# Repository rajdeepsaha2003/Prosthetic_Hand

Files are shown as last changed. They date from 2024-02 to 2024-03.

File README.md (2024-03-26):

# An EMG based cost effective Prosthetic hand 

**Rajdeep Saha, Abhijit Biswas, Saradwat Sen and Sayani Dhali**

**Department of Electronics and Communications Engineering, Supreme Knowledge Foundation Group of Institution, 11, Khan Road, Mankundu, DistrictWest Bengal, Hooghly 712139, India**

**Abstract**   In the era of assistive technology, the need for affordable and accessible prosthetic solutions has been roaming around forever. We introduce the solution by making an inexpensive prosthetic arm controlled by electromyographic (EMG) signals obtained from the upper arm muscles of amputees. This project addresses a major global issue which is, in an estimate over 100 million individuals worldwide require prosthetic limbs due to limb damage or amputation. Unfortunately, a large portion of these individuals (especially those from lower economic backgrounds) face problems accessing due to the high cost of traditional prosthetic options, which can range from Rs70,000 to Rs3.5 lakh for imported prosthetic hands. But this project is Remarkably cost-effective. The overall system costs around a few thousand rupees significantly reducing expenses compared to market alternatives. This project solves the solution by using cost-effective technologies in the most efficient ways. The key component in this prosthetic hand is the Muscle EMG sensor. The noise reduction and the amplification of the Bio-Potential signal is done in the IC of the EMG sensor, which helps in precise signal acquisition. By integrating this sensor into the prosthetic hand design, the component can accurately capture muscle signals and translate them into commands for prosthetic hand movements. The brain of this prosthetic hand is a microcontroller, which serves as the central processing unit for signal processing as Band-Pass Butterworth IIR digital filter and responsiveness. Through confined algorithms and real-time data analysis, the microcontroller reads EMG signals captured by the sensor, enabling full control of the prosthetic hand. This integration of hardware and software makes the project's goal of affordability without compromising performance possible. Beyond the technical aspects, this project solves the topmost prioritized problem which is affordability with efficiency. In third world countries where a large portion of people are suffering through poverty, surgery on amputation is nowhere near possible, let alone installing prosthetics. This cheap but effective alternative which costs around 1-3% of the market's product cost, can be affordable to the mass population with disabilities and enhance their quality of life.

**Keywords:** EMG Signal, Bio-Potential Amplifier, Band-Pass Butterworth IIR digital filter

**1. Introduction**

Prosthetics are artificial devices that compensate for the lack of existence of limbs throughout the body. A prosthetic arm replaces the amputated or inoperative upper limbs. This offers individuals who have lost limbs a chance to regain mobility and independence. Now unlike traditional prosthetic arms, a Myoelectric Prosthetic arm is controllable by myoelectric (EMG) signals expediently. This is made achievable by the fact that amputees' neuro-muscular systems continue to function normally even after amputation. After appropriate processing, the leftover signals are utilized and are sufficient to control the arm's movement. [16]. The technical approach of Sudesh Garg, Kiran Rathi, and Amit Kr. Bansal is concentrated on creating a 3D-printed bionic arm that prioritizes human control via EMG sensors, affordability, and usefulness. It is possible to fabricate objects that are lightweight and customizable by using PLA and 3D printing technology. Evaluating for necessary hand movements guarantees usability and imitation of natural hand movements. The objective is to offer amputees an affordable and easily obtainable option that prioritizes controllability and enhanced quality of life. However, noise filtering methods are not specifically mentioned [9]. Furthermore, to separate muscle signals from outside interference in EMG-based systems, noise filtering techniques are crucial for precise bionic arm control as well as improved user experience and safety.

The research aim focuses on decreasing external noise interference that occurs during signal transmission from the brain to the skin of the targeted muscle location. We successfully reduced this interference by utilizing the Butterworth digital filter, which guarantees more precise and more accurate signal capture. This advanced filtering system is indispensable to improve the prosthetic device's overall reliability and effectiveness.

The merit of the following research lies within the cost factor of the prosthetic arm. It has been estimated that there are roughly 0.62 amputees in India per thousand population [17].  With that number of amputees, we are aware that the traditional EMG-controlled prosthetic’s pricings are way beyond affordable for the lower-income groups. This cheap but efficient controllable prosthetic arm will be viable for every individual regardless of their monetary situation.

In addition, we have added a manually operated radical feature that makes it quite effortless for users to hold a pen and write. With the help of this unique feature, people with upper limb disabilities can now write with greater confidence and ease.

**2. Methodology**

The initial step involves using dry surface electrodes to gather EMG data from the patient's hand. For EMG sensors, three electrodes are employed: two for recording the signal and one as a reference. When targeting specific muscles like the forearm, one electrode is placed at the muscle's center, and the other at a distance of 1.5 inches. The reference electrode is positioned on the bony side or the back side of the forearm. 

To minimize electrode-to-skin impedance, the electrodes are pre-gelled. Before applying the electrodes, the skin is sanitized. The collected EMG data are then analyzed to detect forearm movement and distinguish between hand states such as flexion and extension.[15]

**2.1 Acquisition of signal using Muscle BioAmp Band**

Three electrodes are used here to capture the EMG signal from the muscle of the forearm. Two of them are bipolar surface electrodes and one is a reference electrode. Then the signal is sent to the Muscle BioAmp Candy through BioAmp Cable and then to the Arduino Nano for further processing.
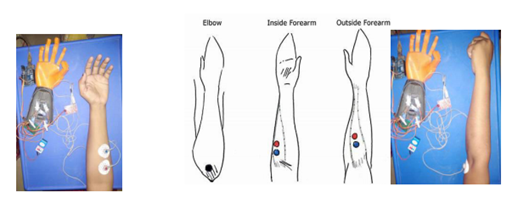
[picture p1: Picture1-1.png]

Figure 1 Electrodes placement for signal acquisition

**2.2 Control of The Prosthetic Hand** 

The prosthetic hand was designed to assist the hand's elbow motions by using signals derived from wrist motions. The EMG signals were processed and then delivered as control signals to an Arduino Nano. Wrist flexion is the signal that is obtained if the person closes their hand or flexes their forearm muscle.

` `This results in the motor rotating in an upward and downward direction, enabling the hands of individuals who are amputated to open and close the hand, and grasp objects. The Arduino Nano's PWM ports are connected to the motor's control input, which is powered by an external source. 

Consequently, the prosthetic hand was successfully operated using EMG signals that were recorded from the healthy hand. [15]

**						

**3. Components and Parts Used**

**3.1 Muscle-BioAmp-Candy**

Muscle-BioAmp-Candy is a candy-sized Electro Myography (EMG) sensor designed to capture precise muscle bio-potential signals. With a compact size and functionality, this device can transform the way of monitoring muscle activity.

It has a fixed gain of x2420 and a Band Pass filter spanning from 72Hz to 720Hz, Muscle-BioAmp-Candy ensures signal clarity and accuracy. 

Compatible with standalone ADCs such as the ADS1115 or any microcontroller development board equipped with an ADC, Muscle-BioAmp-Candy offers seamless integration into your existing setup. [1]

Figure 3 Muscle-BioAmp-Candy [1]

**Schematic Diagram-**

**3.2 Muscle BioAmp Band (EMG Band)**

Stretchable in nature, the Muscle BioAmp Band (EMG Band) can be linked to the Muscle BioAmp-Candy via a BioAmp Cable that uses dry electrodes. It makes it simple for you to capture your muscle signals.[14]

**Dimensions:**

**			 

**Features & Specifications**

Length: 13 inches

Stretchability: 2X (up to 26 inches)

Usability: Reusable as it comes with washable fabric

Interface: Snap electrodes

Compatible Hardware: BioAmp Cable used with BioAmp Hardware (Muscle BioAmp BisCute, Muscle BioAmp Candy, Muscle BioAmp Patchy, BioAmp EXG Pill, Muscle BioAmp Shield)

BioPotentials: EMG

No. of channels: 1

Wearable: Yes

Figure 6 Electrode Placement Example [14]

**3.2** **Arduino Nano**

Figure 7 Arduino Nano Board [2]

Arduino Nano is a small, breadboard-friendly development board based on an ATmega 328P SMD package microcontroller and offers the same connectivity and specs as Arduino Uno in a small package. In our project, we are using it because the size is the main factor. After all, the microcontroller needs to be fit into the 3d printed hand. We are supplying the power to the board with a Mini B USB port present on it. [2]

**Specifications:**

- It has 22 I/O pins in total of which 14 are Digital (6 are PWM output) and 8 are Analog pins.
- Operating Voltage (Logic Level): 5V.
- Supports Serial, I2C, SPI Communication Protocols.
- Flash memory: 32KB in which 2KB is used by Bootloader
- Clock speed: 16MHz
- DC Current per I/O Pin: 40 mA
- SRAM: 2KB, EEPROM: 1KB
- DC Current per I/O pin: 40mA[2]

**3.3 SG90 9 g Micro Servo**

Figure 8 SG90 9 g Micro Servo [3]*			Figure 9 Orthographic view of SG90 9 g Micro Servo [3]

SG90 9 g Micro Servo is tiny and lightweight with high output power. The servo motors are used for the movement of the fingers in the hand. The servo motors usually provide control over the 180° range. This angular position control is controlled by the PWM technique so by varying its duty cycle we can control the angular position of the motor. This servo motor can lift a maximum of 1.6 kg when suspended at a 1cm distance from the shaft. [3]

Specifications

• Weight: 9 g

• Dimension: 22.2 x 11.8 x 31 mm approx.

• Stall torque: 1.8 kgf·cm

• Operating speed: 0.1 s/60 degree

• Operating voltage: 4.8 V (~5V)

• Dead band width: 10 µs 

• Temperature range: 0 ºC – 55 ºC [3]

` `Every 20 ms, the servo examines the pulse. The servo can be rotated to zero degrees by a pulse with a width of 1 ms (1 millisecond), to ninety degrees (the neutral position) by a pulse of 1.5 ms, and to 180 degrees by a pulse of 2 ms.. [13]

**3.4 Power Bank**

Figure 11 Reconnect Power Hub 10000 mAh Power Bank Series 100 [4]

Here we are using Reconnect Power Hub 10000 mAh Power Bank Series 100. It has a capacity of 10000 mAh, so it can be used for longer intervals. As the microcontroller, servo, and Muscle-BioAmp-Candy draw very little power on a full charge it lasts for about 10hrs.[4]

Specifications and Features

- Over Charge Protection, Over Discharge Protection
- Over Current Protection, Short Circuit Protection
- Input: 5V 2A(max)
- Type C And Micro USB Dual Input Port
- USB A 5V/2A Output Port
- BIS Certified [4]

**3.5 Fabrication of 3D Printed Hand**

Here we used PLA because PLA is a common 3D printing material to print components. PLA is widely used because of its ease of availability, ecological footprint, and affordability. 
PLA is a biodegradable substance derived from food crops like sugarcane, corn, and jowar. Here are some key characteristics of PLA and the 3D printer [9]:

**Table 1:** Features of PLA[9][10]

|**S.N.**|**Property**|**Value**|
| :-: | :-: | :-: |
|1|Melting Point|Low (150°C and 180°C)|
|2|Thermal Expansion|Low (68 µm/m-K )|
|3|Layer Adhesion|Moderate|
|4|Heat Resistance|Low(55–65 °C)|
|5|Tensile Strength|High(39.9 MPa to 52.5 MPa)|
|6|Compressive Strength|High (48.2 MPa to 62.0 MPa)|
|7|Dimensional Accuracy|High|

**Table 2:** Features of 3D Printer[11]

|**Model**|**Ender 3**|
| :-: | :-: |
|Physical dimensions|(w) 40 cm x (d) 22 cm x (h) 46 cm|
|Maximum printing area|(w) 20 cm x (d) 22 cm x (h) 22 cm|
|Wire diameter|0\.2mm|
|Nozzle diameter|0\.4mm|
|Platform temperature|~100 °C|
|Nozzle printing temperature|~200 °C|
|Cooling method|Air Cool|
|Motor drive|Stepper Motor Drive|

Now let us discuss the specification of the 3D Printed Hand

**Table 3:** Technical Specification of 3D Printed Parts[12]

|**No.**|**Name of the parts**|**No. of joints/parts**|**Length (cm)**|
| :- | :- | :- | :- |
|1|Thumb finger|2|5\.5|
|2|Index finger|3|6|
|3|Middle finger|3|8\.5|
|4|Ring finger|3|7\.5|
|5|Pinky finger|3|5\.5|
|6|Palm|1|10|
|7|Wrist|-|2\.3|
|8|The diameter of the end of the wrist|-|10|
|9|The total length of the arm|-|30|

Figure 12 Isometric projection of the 3D Printed Hand [11]

**4 Algorithms and Their Detailed Analysis**

**4.1 Algorithm of the Arduino Code**

**Initialization:**

1. Set up the system parameters including the header files, sampling rate, baud rate, and pin configurations.
1. Initialize the communication interfaces (e.g., Serial) for monitoring and debugging purposes.

**Setup:**

1. Attach the servo motors to their respective pins and set their initial positions.
1. Define the WritePin
1. Configure the EMG sensor input pin and any auxiliary pins required for system operation.
1. Define the threshold voltage (different for each person)

**Main Loop:**

1. Check WritePin is High or Low 

If High, Rotate the thumb, index, and middle finger as such it can hold a pen for writing purposes

If Low, Continue to the next steps

1. Continuously sample the EMG signal at the defined sampling rate.
1. Apply a band-pass Butterworth IIR digital filter to the raw EMG signal to extract relevant muscle activity within the desired frequency range.
1. Compute the EMG envelope using an envelope detection algorithm to estimate the magnitude of muscle activation.

**Gesture Recognition:**

1. Compare the normalized envelope value with a predefined threshold to determine muscle activation and gesture recognition.
1. Implement a hysteresis mechanism to prevent rapid toggling of the hand due to noise or minor fluctuations in muscle activity.
1. Define specific thresholds for opening and closing gestures based on individual user characteristics and preferences.

**Servo Control:**

1. Based on the detected gesture:
   1. If the muscle activation exceeds the closing threshold:
      1. Close the hand by rotating the servo motors to the predefined closed position.
   1. If the muscle activation falls below the opening threshold:
      1. Open the hand by rotating the servo motors to the predefined open position.
1. Implement a gesture delay to prevent rapid and unintended toggling of the claw in response to minor fluctuations in muscle activity. [1]

**4.2 Algorithm for Envelope Detection-**

1. Subtract the previous EMG signal value from the sum.
1. Add the absolute value of the current EMG signal to the sum.
1. Store the absolute value of the current EMG signal in the circular buffer at the current index.
1. Update the data index to point to the next position in the circular buffer, wrapping around to the beginning if necessary.
1. Compute the average of the EMG signal values in the circular buffer by dividing the sum by the buffer size.
1. Multiply the average by 2 to scale the envelope signal.
1. Return the computed envelope signal.

Figure 14 EMG Signal After Filter with The Detected Envelope [9]

**4.3 Algorithm of EMG Band Pass Filter**

Algorithm for the Band-Pass Butterworth IIR digital filter:

1. **Initialization**:
   1. Initialize the state variables **z1** and **z2** for each filter section to zero.
1. **Filtering Process**:
   1. For each input sample:
      1. For each filter section:
         1. Calculate the intermediate variable **x** using the difference equation of a second-order IIR filter.
         1. Update the output using the calculated **x** value and the previous state variables.
         1. Update the state variables **z1** and **z2** for the next iteration.
1. **Output**:
   1. Return the filtered output.

Here's a breakdown of the steps within the filtering process:

- For each filter section:
  - Calculate the intermediate variable **x** using the difference equation:

x = input - a1 \* z1 - a2 \* z2 

where **input** is the current input sample, **z1,** and **z2** are the previous state variables, and **a1** and **a2** are the filter coefficients.

- Update the output using the calculated **x** value and the previous state variables:

output = b0 \* x + b1 \* z1 + b2 \* z2 

where **b0**, **b1**, and **b2** are the filter coefficients for the output.

- Update the state variables **z1** and **z2** for the next iteration:

z2 = z1 z1 = x 

Repeating these steps for each input sample, obtained the filtered output of the Band-Pass Butterworth IIR digital filter. [1] [5] [6]

**4.4 General Difference Equation of** **Band-Pass Butterworth IIR digital filter**

The code implements a Band-Pass Butterworth IIR digital filter using second-order sections (biquads). Each biquad represents a second-order IIR filter section. Let's break down the mathematical expression for each biquad.

The general difference equation for a second-order IIR filter is:

*y*[*n*]=*b*<sub>0</sub>*x*[*n*]+*b*<sub>1</sub>*x*[*n*−1]+*b*<sub>2</sub>*x*[*n*−2]−*a*<sub>1</sub>*y*[*n*−1]−*a*<sub>2</sub>*y*[*n*−2]

Where:

- *y*[*n*] is the output at time *n*
- *x*[*n*] is the input at time *n*
- *x*[*n*−1] and *x*[*n*−2] are the previous input samples
- *y*[*n*−1] and *y*[*n*−2] are the previous output samples
- *b*<sub>0</sub>,*b*<sub>1</sub>,*b*<sub>2</sub> are the feedforward (numerator) coefficients
- *a*<sub>1</sub>,*a*<sub>2</sub> are the feedback (denominator) coefficients

Let's express each biquad in the code as difference equations:

**First Biquad:**

z1\_1[n] = x[n] - 0.05159732 \* z1\_1[n-1] - 0.36347401 \* z2\_1[n-1] z2\_1[n] = z1\_1[n-1] y\_1[n] = 0.01856301 \* z1\_1[n] + 0.03712602 \* z2\_1[n] + 0.01856301 \* z2\_1[n-1] 

**Second Biquad:**

z1\_2[n] = y\_1[n] - (-0.53945795 \* z1\_2[n-1] - 0.39764934 \* z2\_2[n-1]) z2\_2[n] = z1\_2[n-1] y\_2[n] = 1.00000000 \* z1\_2[n] - 2.00000000 \* z1\_2[n-1] + 1.00000000 \* z2\_2[n-1] 

**Third Biquad:**

z1\_3[n] = y\_2[n] - (0.47319594 \* z1\_3[n-1] - 0.70744137 \* z2\_3[n-1]) z2\_3[n] = z1\_3[n-1] y\_3[n] = 1.00000000 \* z1\_3[n] + 2.00000000 \* z1\_3[n-1] + 1.00000000 \* z2\_3[n-1] 

**Fourth Biquad:**

z1\_4[n] = y\_3[n] - (-1.00211112 \* z1\_4[n-1] - 0.74520226 \* z2\_4[n-1]) z2\_4[n] = z1\_4[n-1] y\_4[n] = 1.00000000 \* z1\_4[n] - 2.00000000 \* z1\_4[n-1] + 1.00000000 \* z2\_4[n-1] 

Where:

- <i>z</i>1<i><sub>i</sub></i>[<i>n</i>] and <i>z</i>2<sub><i>i</i></sub>[<i>n</i>] are the state variables for the <i>i</i>-th biquad at time <i>n</i>
- *x*[*n*] is the input at time *n*
- <i>y<sub>i</sub></i>[<i>n</i>] is the output of the <i>i</i>-th biquad at time <i>n</i>

This set of equations describes the mathematical expression for the given Band-Pass Butterworth IIR digital filter implemented in the provided code. Each biquad contributes to the overall filter response, and the output of one biquad serves as the input to the next biquad in the chain.[5] [6] [7][8]

**4.5 Simulation of BPF in MATLAB**

Here we have simulated the Band-Pass Butterworth IIR digital filter in MATLAB. First we have shown the unfiltered EMG signal acquired from the hand which consists of different frequencies(45Hz, 60Hz, 90Hz, 100Hz and 160Hz) and noise.

Figure 15 Raw EMG signal with multiple frequencies of 45Hz, 60Hz, 90Hz, 100Hz and 160Hz [5][6] [7][8]

And here we have shown the EMG signal after passing through the Band-Pass Butterworth IIR digital filter.

Figure 16 Filtered EMG Signal after Band Pass Filter consisting of frequencies 90Hz and 100Hz [5][6][7][8]

And this is the frequency response of the Band-Pass Butterworth IIR digital filter with -3db point which has a sampling rate: 500.0 Hz, cutoff frequency: [74.5, 149.5] Hz[5][6] [7][8]

Figure 17 Frequency response of the Band-Pass Butterworth IIR digital filter with -3db point [5][6] [7][8]

**5. Testing and Results**

We tested the prosthetic hand with 10 people who have healthy hands and we got these accurate results. We tested 3 things here first how accurately it can grab an object then how accurately it can close and open the hand. 

To have better gripping capability we used hot glue to have a better gripping capability in the most probable contact points when trying to grab any object.

Here are some images that shows how the prosthetic hand looks when at rest and flexed.

Figure 19 Hand at Flexed (Close) Position

To test the accuracy of grabbing any object we have used a round object and a cylindrical object as shown in the Figure 20 and Figure 21.

Now here are the results that we got after testing it on 10 people with heathy hands.

Figure 22 Accuracy of Grabbing Any Object With the Prosthetic Hand

Figure 23 Accuracy of Closing and Opening the Prosthetic Hand

**6. Conclusion**

**References**

1\. GitHub - upsidedownlabs/Muscle-BioAmp-Candy: A candy size ElectroMyoGraphy (EMG) sensor for precise muscle bio-potential signals recording. (n.d.). GitHub. <https://github.com/upsidedownlabs/Muscle-BioAmp-Candy>

2\. Arduino Nano  - Soldered (Without Cable). (n.d.). QuartzComponents. <https://quartzcomponents.com/products/arduino-nano-v3-0-soldered-without-cable?_pos=2&_sid=2bf3b65a9&_ss=r>

3\. SG90 Servo Motor Datasheet. (n.d.). https://components101.com/. Retrieved March 24, 2024, from <https://components101.com/sites/default/files/component_datasheet/SG90%20Servo%20Motor%20Datasheet.pdf>

4\. Reconnect Marvel Spiderman 10000mAh PowerBank, Li-Po battery, 1 USBB output port, Micro USB & Type C dual input, BIS approved, Mobile Accessories- DPB102 SM Online at Best Prices in India - JioMart. (n.d.). JioMart. https://www.jiomart.com/p/electronics/reconnect-marvel-spiderman-10000mah-powerbank-li-po-battery-1-usbb-output-port-micro-usb-type-c-dual-input-bis-approved-mobile-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

5\. scipy.signal.butter — SciPy v1.12.0 Manual. (n.d.). <https://docs.scipy.org/doc/scipy/reference/generated/scipy.signal.butter.html>

6\. Iyer, S. V. (2020, November 30). Digital Filter Design using Python for Power Engineering Applications. Springer Nature. <http://books.google.ie/books?id=jx8MEAAAQBAJ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>

7\. Verma, N. K., & Ghosh, A. K. (2018, July 31). *Computational Intelligence: Theories, Applications and Future Directions - Volume I*. Springer. <http://books.google.ie/books?id=i_pmDwAAQBAJ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>

8\. *Digital filter*. (2023, December 11). Wikipedia. https://en.wikipedia.org/wiki/Digital\_filter#Direct\_form\_II

9\. Garg, S., Rathi, K., & Bansal, A. K. (2023, April 1). Development of 3D Printed Bionic Arm Controlled by EMG Sensor. SKIT Research Journal, 13(1), 13–18. <https://doi.org/10.47904/ijskit.13.1.2023.13-18>

10\. Gao, G., Xu, F., Xu, J., & Liu, Z. (2022, October 10). Study of Material Color Influences on Mechanical Characteristics of Fused Deposition Modeling Parts. *Materials*, *15*(19), 7039. https://doi.org/10.3390/ma15197039

11\. Hsueh, M. H., Lai, C. J., Wang, S. H., Zeng, Y. S., Hsieh, C. H., Pan, C. Y., & Huang, W. C. (2021, May 27). Effect of Printing Parameters on the Thermal and Mechanical Properties of 3D-Printed PLA and PETG, Using Fused Deposition Modeling. *Polymers*, *13*(11), 1758. https://doi.org/10.3390/polym13111758

12\. Sakib, N., & Islam, M.K. (2019). Design and Implementation of an EMG Controlled 3D Printed Prosthetic Arm. *2019 IEEE International Conference on Biomedical Engineering, Computer and Information Technology for Health (BECITHCON)*, 85-88.

13\. *What is a Servo Motor? - Understanding the basics of Servo Motor Working*. (n.d.). <https://circuitdigest.com/article/servo-motor-working-and-basics>

14\. *Muscle BioAmp Band (EMG Band) | Upside Down Labs Store*. (2024, March 18). Upside Down Labs Store. https://store.upsidedownlabs.tech/product/muscle-bioamp-band/

15\. (2021). EMG sensor based control strategy for hand function movements using 3D prosthetic hand . *Journal of Cardiovascular Disease Research*, *12*(03), Article 0975–3583, 0976–2833. https://jcdronline.org/admin/Uploads/Files/624418536e9b14.69166253.pdf

16\. Jun-Uk Chu, Member, IEEE, Inhyuk Moon,” A Supervised Feature-Projection-Based Real-Time EMG Pattern Recognition for Multifunction Myoelectric Hand Control“, IEEE/ASME Transactions on Mechatronics, vol. 12, no. 3, June 2007, p. 282-290

17\. *A Report on Amputees in India | O&P Virtual Library*. (n.d.). <https://www.oandplibrary.org/op/1986_01_016.asp>

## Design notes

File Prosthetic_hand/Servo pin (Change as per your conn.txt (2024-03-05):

// Servo pin (Change as per your connection)
THUMB_PIN D2 
INDEX_PIN D3
MIDD_PIN D5
RING_PIN D6
PINKY_PIN D9

// Pin for writing
writePin D10
#define writeEN 11

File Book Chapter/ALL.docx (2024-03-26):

An EMG based cost effective Prosthetic hand

Rajdeep Saha, Abhijit Biswas, Saradwat Sen and Sayani Dhali

Department of Electronics and Communications Engineering, Supreme Knowledge Foundation Group of Institution, 1, Khan Road, Mankundu, West Bengal, Hooghly 712139, India

Abstract In the era of assistive technology, the need for affordable and accessible prosthetic solutions has been roaming around forever. We introduce the solution by making an inexpensive prosthetic arm controlled by electromyographic (EMG) signals obtained from the upper arm muscles of amputees. This project addresses a major global issue which is, in an estimate over 100 million individuals worldwide require prosthetic limbs due to limb damage or amputation. Unfortunately, a large portion of these individuals (especially those from lower economic backgrounds) face problems accessing due to the high cost of traditional prosthetic options, which can range from Rs70,000 to Rs3.5 lakh for imported prosthetic hands. But this project is Remarkably cost-effective. The overall system costs around a few thousand rupees significantly reducing expenses compared to market alternatives. This project solves the solution by using cost-effective technologies in the most efficient ways. The key component in this prosthetic hand is the Muscle EMG sensor. The noise reduction and the amplification of the Bio-Potential signal is done in the IC of the EMG sensor, which helps in precise signal acquisition. By integrating this sensor into the prosthetic hand design, the component can accurately capture muscle signals and translate them into commands for prosthetic hand movements. The brain of this prosthetic hand is a microcontroller, which serves as the central processing unit for signal processing as Band-Pass Butterworth IIR digital filter and responsiveness. Through confined algorithms and real-time data analysis, the microcontroller reads EMG signals captured by the sensor, enabling full control of the prosthetic hand. This integration of hardware and software makes the project's goal of affordability without compromising performance possible. Beyond the technical aspects, this project solves the topmost prioritized problem which is affordability with efficiency. In third world countries where a large portion of people are suffering through poverty, surgery on amputation is nowhere near possible, let alone installing prosthetics. This cheap but effective alternative which costs around 1-3% of the market's product cost, can be affordable to the mass population with disabilities and enhance their quality of life.

Keywords: EMG Signal, Bio-Potential Amplifier, Band-Pass Butterworth IIR digital filter

1. Introduction

Prosthetics are artificial devices that compensate for the lack of existence of limbs throughout the body. A prosthetic arm replaces the amputated or inoperative upper limbs. This offers individuals who have lost limbs a chance to regain mobility and independence. Now unlike traditional prosthetic arms, a Myoelectric Prosthetic arm is controllable by myoelectric (EMG) signals expediently. This is made achievable by the fact that amputees' neuro-muscular systems continue to function normally even after amputation. After appropriate processing, the leftover signals are utilized and are sufficient to control the arm's movement. [16]. The technical approach of Sudesh Garg, Kiran Rathi, and Amit Kr. Bansal is concentrated on creating a 3D-printed bionic arm that prioritizes human control via EMG sensors, affordability, and usefulness. It is possible to fabricate objects that are lightweight and customizable by using PLA and 3D printing technology. Evaluating for necessary hand movements guarantees usability and imitation of natural hand movements. The objective is to offer amputees an affordable and easily obtainable option that prioritizes controllability and enhanced quality of life. However, noise filtering methods are not specifically mentioned [9]. Furthermore, to separate muscle signals from outside interference in EMG-based systems, noise filtering techniques are crucial for precise bionic arm control as well as improved user experience and safety.

The research aim focuses on decreasing external noise interference that occurs during signal transmission from the brain to the skin of the targeted muscle location. We successfully reduced this interference by utilizing the Butterworth digital filter, which guarantees more precise and more accurate signal capture. This advanced filtering system is indispensable to improve the prosthetic device's overall reliability and effectiveness.

The merit of the following research lies within the cost factor of the prosthetic arm. It has been estimated that there are roughly 0.62 amputees in India per thousand population [17]. With that number of amputees, we are aware that the traditional EMG-controlled prosthetic’s pricings are way beyond affordable for the lower-income groups. This cheap but efficient controllable prosthetic arm will be viable for every individual regardless of their monetary situation.

In addition, we have added a manually operated radical feature that makes it quite effortless for users to hold a pen and write. With the help of this unique feature, people with upper limb disabilities can now write with greater confidence and ease.

2. Methodology

The initial step involves using dry surface electrodes to gather EMG data from the patient's hand. For EMG sensors, three electrodes are employed: two for recording the signal and one as a reference. When targeting specific muscles like the forearm, one electrode is placed at the muscle's center, and the other at a distance of 1.5 inches. The reference electrode is positioned on the bony side or the back side of the forearm.

To minimize electrode-to-skin impedance, the electrodes are pre-gelled. Before applying the electrodes, the skin is sanitized. The collected EMG data are then analyzed to detect forearm movement and distinguish between hand states such as flexion and extension.[15]

2.1 Acquisition of signal using Muscle BioAmp Band

Three electrodes are used here to capture the EMG signal from the muscle of the forearm. Two of them are bipolar surface electrodes and one is a reference electrode. Then the signal is sent to the Muscle BioAmp Candy through BioAmp Cable and then to the Arduino Nano for further processing.

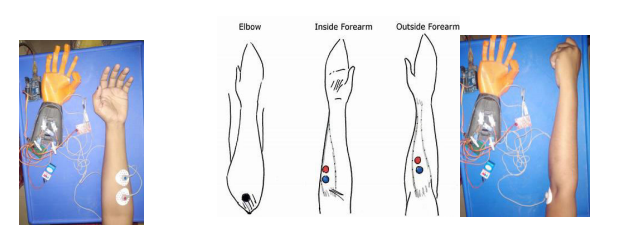
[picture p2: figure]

Figure 1 Electrodes placement for signal acquisition

2.2 Control of The Prosthetic Hand

The prosthetic hand was designed to assist the hand's elbow motions by using signals derived from wrist motions. The EMG signals were processed and then delivered as control signals to an Arduino Nano. Wrist flexion is the signal that is obtained if the person closes their hand or flexes their forearm muscle.

This results in the motor rotating in an upward and downward direction, enabling the hands of individuals who are amputated to open and close the hand, and grasp objects. The Arduino Nano's PWM ports are connected to the motor's control input, which is powered by an external source.

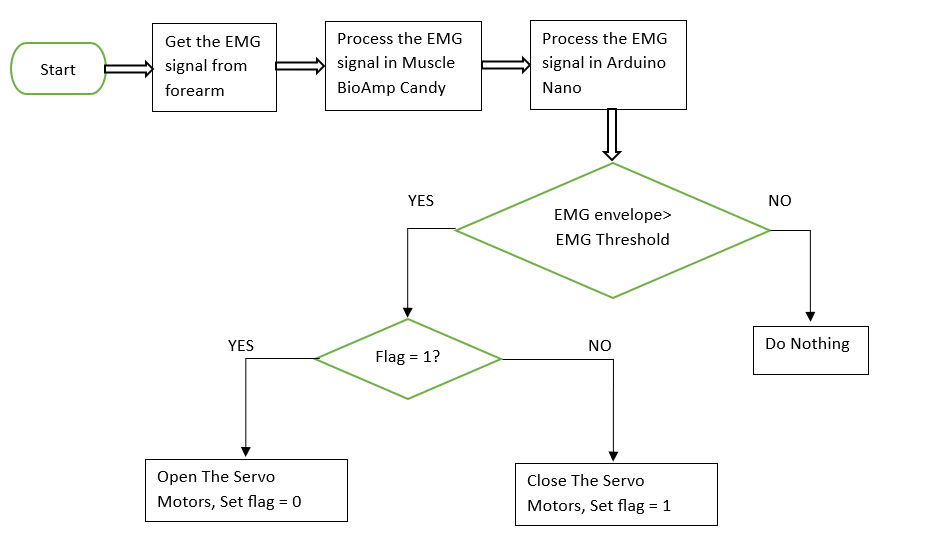
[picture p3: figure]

Consequently, the prosthetic hand was successfully operated using EMG signals that were recorded from the healthy hand. [15]

Figure 2 Flow diagram of the process

2.3 Circuit Diagram

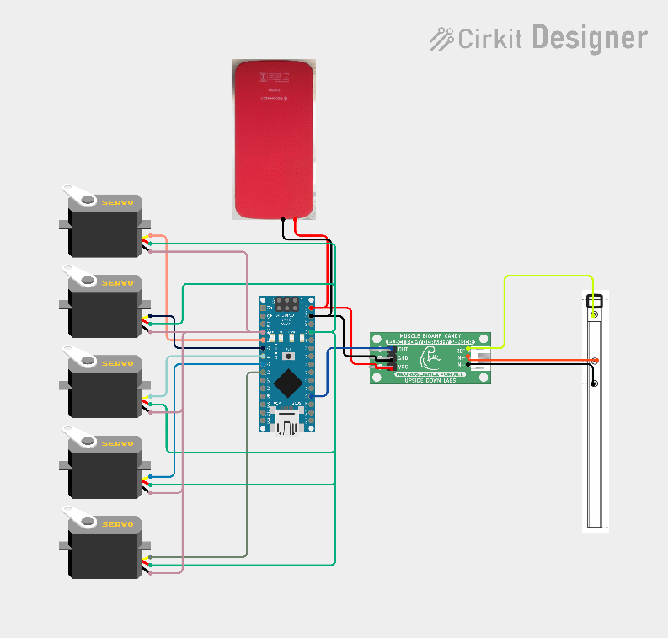
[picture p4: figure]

Figure 3 Circuit Diagram of The Prosthetic Hand

Now lets discuss about the circuitry and power management system utilized in our project. The whole system has 5 servo motors for accurate finger movement, an EMG sensor for muscle signal acquisition, and a power bank for portable operation. Each component's connections to the Arduino Nano microcontroller are discussed below in this project.

Servo Motors (Thumb, Index, Middle, Ring, Pinky):

  - Each servo motor is connected to the Arduino Nano for control.
  - Signal wires (usually PWM) from each servo are connected to digital pins (D2, D3, D4, D5, D6) of the Arduino Nano.
  - Power for each servo is drawn from the 5V port of the Arduino Nano.
  - Ground connections for each servo are made to the GND port of the Arduino Nano.

Power Management (Power Bank):

  - The power bank used is a "Reconnect Power Hub 10000 mAh Power Bank Series 100".
  - The power bank is connected to the Arduino Nano via its USB port, providing power to the entire system.

Muscle BioAmp Candy(EMG Sensor):

  - The EMG sensor used is a "Muscle BioAmp Candy".
  - The output side of the EMG sensor is connected to the Arduino Nano.
    - The analog output (Out) of the EMG sensor is connected to analog pin A0 of the Arduino Nano.
    - Ground (GND) of the EMG sensor is connected to the GND port of the Arduino Nano.
    - VCC (power) of the EMG sensor is connected to the Vin port of the Arduino Nano.
  - The input side of the EMG sensor is connected to the EMG band.
    - REF, IN+, and IN- ports of the EMG band are connected accordingly to the REF, IN+, and IN- ports of the EMG sensor.

This circuit diagram effectively illustrates the interconnection of components within the

EMG-controlled prosthetic hand system

3. Components and Parts Used

3.1 Muscle-BioAmp-Candy

Muscle-BioAmp-Candy is a candy-sized Electro Myography (EMG) sensor designed to capture precise muscle bio-potential signals. With a compact size and functionality, this device can transform the way of monitoring muscle activity.

It has a fixed gain of x2420 and a Band Pass filter spanning from 72Hz to 720Hz, Muscle-BioAmp-Candy ensures signal clarity and accuracy.

Compatible with standalone ADCs such as the ADS1115 or any microcontroller development board equipped with an ADC, Muscle-BioAmp-Candy offers seamless integration into your existing setup. [1]

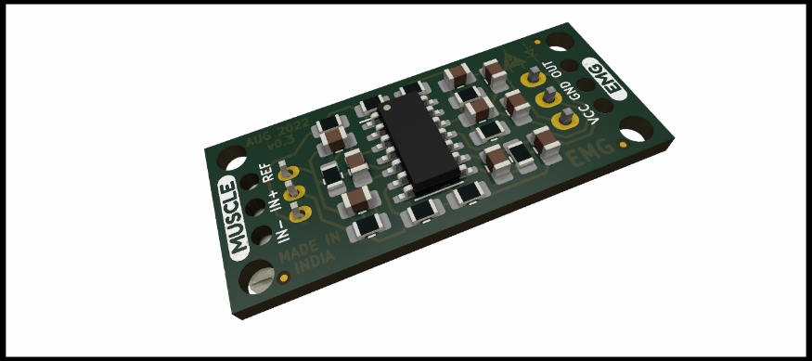
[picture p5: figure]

Figure 4 Muscle-BioAmp-Candy [1]

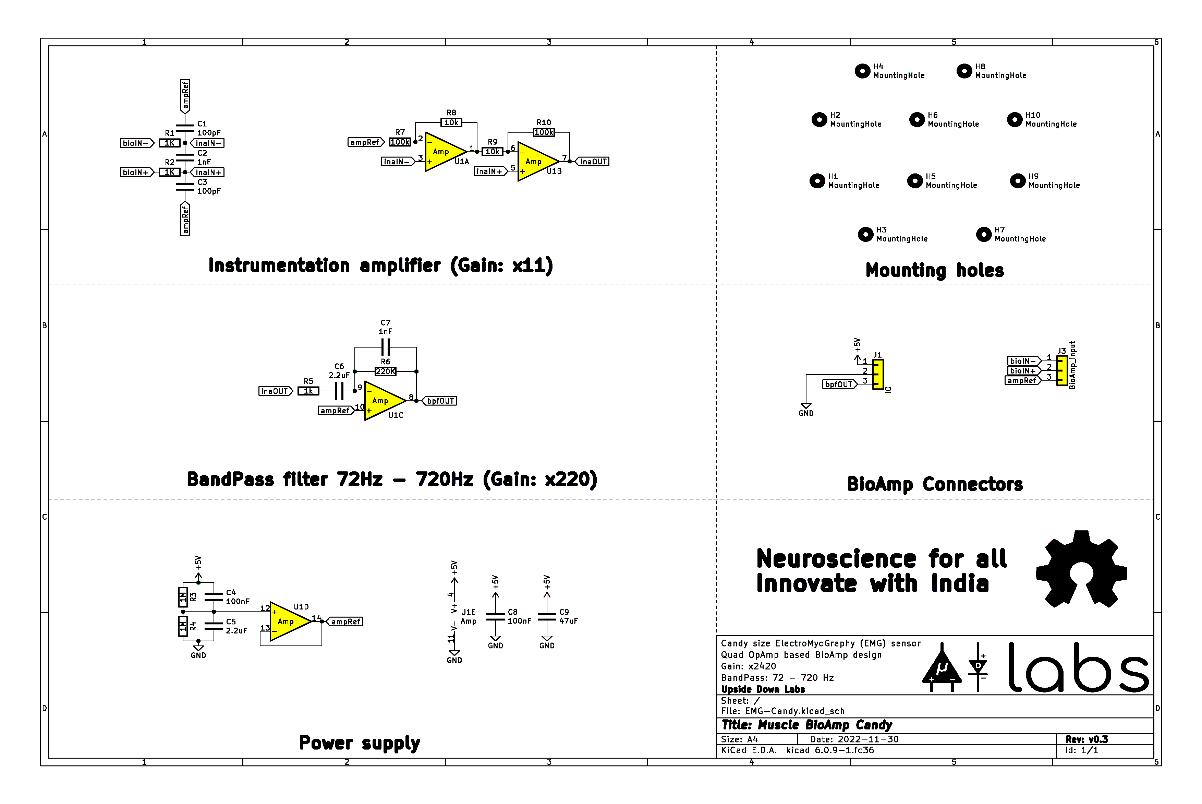
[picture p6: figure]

Schematic Diagram-

Figure 5 Schematic diagram of Muscle-BioAmp-Candy [1]

3.2 Muscle BioAmp Band (EMG Band)

Stretchable in nature, the Muscle BioAmp Band (EMG Band) can be linked to the Muscle BioAmp-Candy via a BioAmp Cable that uses dry electrodes. It makes it simple for you to capture your muscle signals.[14]

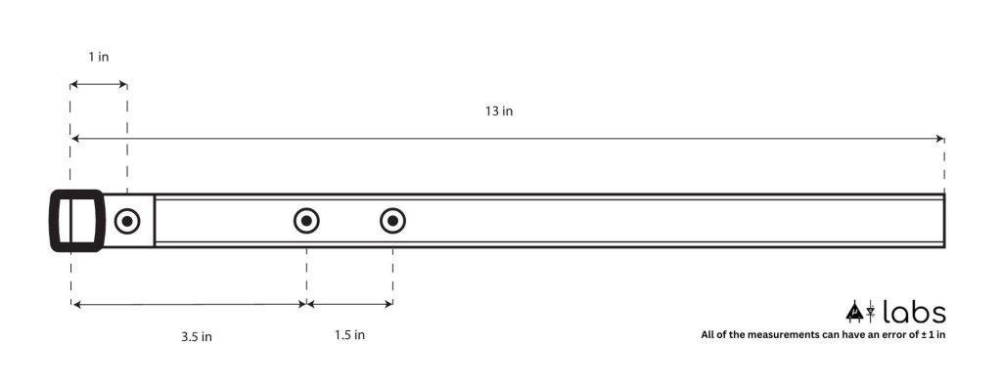
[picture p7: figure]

Dimensions:

Figure 6 Dimensions of the Muscle BioAmp Band (EMG Band) [14]

Features & Specifications

Length: 13 inches

Stretchability: 2X (up to 26 inches)

Usability: Reusable as it comes with washable fabric

Interface: Snap electrodes

No. of channels: 1

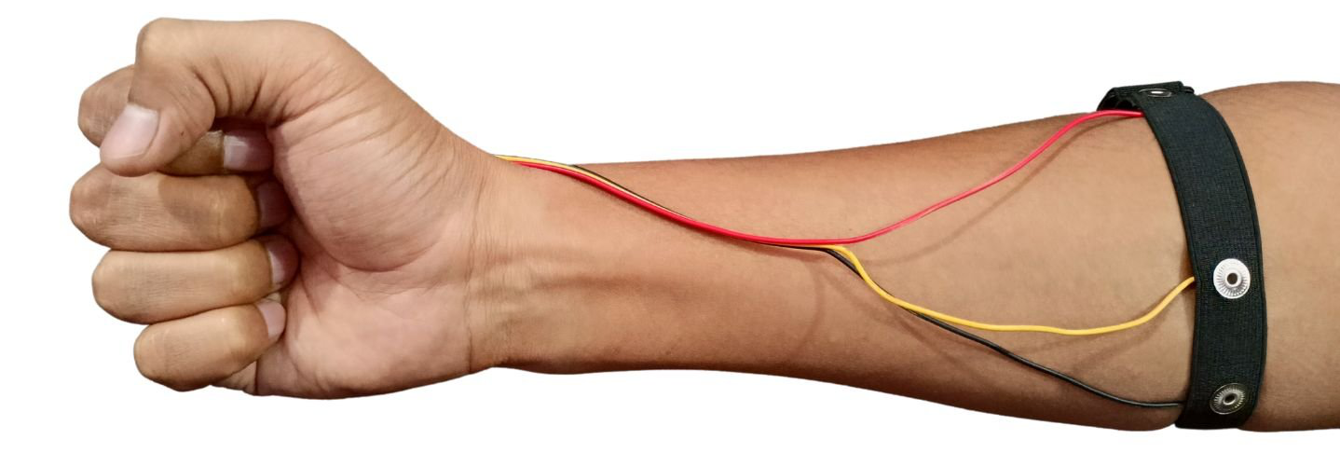
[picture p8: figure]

Figure 7 Electrode Placement Example [14]

3.2 Arduino Nano

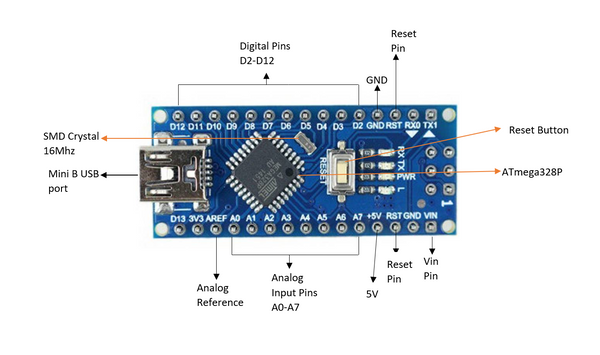
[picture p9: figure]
Arduino Nano Simplified Pinout

Figure 8 Arduino Nano Board [2]

Arduino Nano is a small, breadboard-friendly development board based on an ATmega 328P SMD package microcontroller and offers the same connectivity and specs as Arduino Uno in a small package. In our project, we are using it because the size is the main factor. After all, the microcontroller needs to be fit into the 3d printed hand. We are supplying the power to the board with a Mini B USB port present on it. [2]

Specifications:

- It has 22 I/O pins in total of which 14 are Digital (6 are PWM output) and 8 are Analog pins.
- Operating Voltage (Logic Level): 5V.
- Supports Serial, I2C, SPI Communication Protocols.
- Flash memory: 32KB in which 2KB is used by Bootloader
- Clock speed: 16MHz
- DC Current per I/O Pin: 40 mA
- SRAM: 2KB, EEPROM: 1KB
- DC Current per I/O pin: 40mA[2]

3.3 SG90 9 g Micro Servo

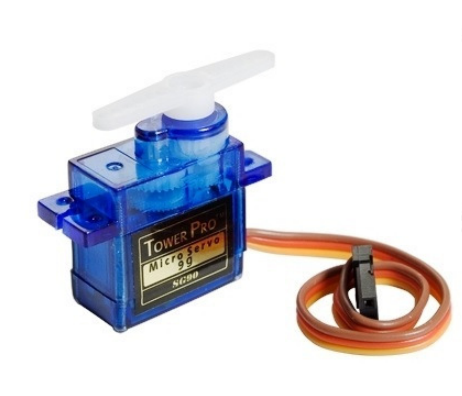
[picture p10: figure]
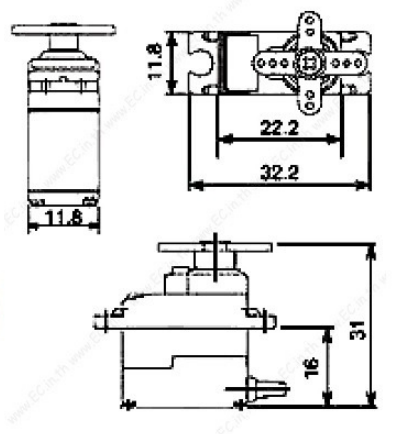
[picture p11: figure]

Figure 9 SG90 9 g Micro Servo [3] Figure 10 Orthographic view of SG90 9 g Micro Servo [3]

SG90 9 g Micro Servo is tiny and lightweight with high output power. The servo motors are used for the movement of the fingers in the hand. The servo motors usually provide control over the 180° range. This angular position control is controlled by the PWM technique so by varying its duty cycle we can control the angular position of the motor. This servo motor can lift a maximum of 1.6 kg when suspended at a 1cm distance from the shaft. [3]

Specifications

• Weight: 9 g

• Dimension: 22.2 x 11.8 x 31 mm approx.

• Stall torque: 1.8 kgf·cm

• Operating speed: 0.1 s/60 degree

• Operating voltage: 4.8 V (~5V)

• Dead band width: 10 µs

• Temperature range: 0 ºC – 55 ºC [3]

Every 20 ms, the servo examines the pulse. The servo can be rotated to zero degrees by a pulse with a width of 1 ms (1 millisecond), to ninety degrees (the neutral position) by a pulse of 1.5 ms, and to 180 degrees by a pulse of 2 ms.. [13]

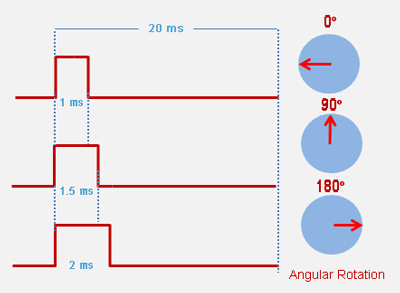
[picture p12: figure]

Figure 11 Rotation control of SG90 9 g Micro Servo [13]

3.4 Power Bank

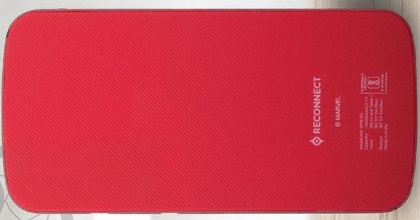
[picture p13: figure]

Figure 12 Reconnect Power Hub 10000 mAh Power Bank Series 100 [4]

Here we are using Reconnect Power Hub 10000 mAh Power Bank Series 100. It has a capacity of 10000 mAh, so it can be used for longer intervals. As the microcontroller, servo, and Muscle-BioAmp-Candy draw very little power on a full charge it lasts for about 10hrs.[4]

Specifications and Features

- Over Charge Protection, Over Discharge Protection
- Over Current Protection, Short Circuit Protection
- Input: 5V 2A(max)
- Type C And Micro USB Dual Input Port
- USB A 5V/2A Output Port
- BIS Certified [4]

3.5 Fabrication of 3D Printed Hand

Here we used PLA because PLA is a common 3D printing material to print components. PLA is widely used because of its ease of availability, ecological footprint, and affordability.
PLA is a biodegradable substance derived from food crops like sugarcane, corn, and jowar. Here are some key characteristics of PLA and the 3D printer [9]:

Table 1: Features of PLA[9][10]

S.N. | Property | Value
1 | Melting Point | Low (150°C and 180°C)
2 | Thermal Expansion | Low (68 µm/m-K )
3 | Layer Adhesion | Moderate
4 | Heat Resistance | Low(55–65 °C)
5 | Tensile Strength | High(39.9 MPa to 52.5 MPa)
6 | Compressive Strength | High (48.2 MPa to 62.0 MPa)
7 | Dimensional Accuracy | High

Table 2: Features of 3D Printer[11]

Model | Ender 3
Physical dimensions | (w) 40 cm x (d) 22 cm x (h) 46 cm
Maximum printing area | (w) 20 cm x (d) 22 cm x (h) 22 cm
Wire diameter | 0.2mm
Nozzle diameter | 0.4mm
Platform temperature | ~100 °C
Nozzle printing temperature | ~200 °C
Cooling method | Air Cool
Motor drive | Stepper Motor Drive

Now let us discuss the specification of the 3D Printed Hand

Table 3: Technical Specification of 3D Printed Parts[12]

No. | Name of the parts | No. of joints/parts | Length (cm)
1 | Thumb finger | 2 | 5.5
2 | Index finger | 3 | 6
3 | Middle finger | 3 | 8.5
4 | Ring finger | 3 | 7.5
5 | Pinky finger | 3 | 5.5
6 | Palm | 1 | 10
7 | Wrist | - | 2.3
8 | The diameter of the end of the wrist | - | 10
9 | The total length of the arm | - | 30

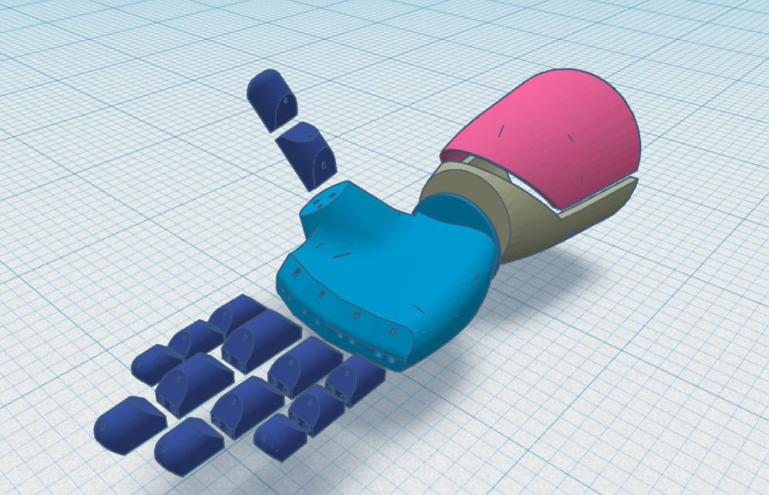
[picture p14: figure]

Figure 13 Isometric projection of the 3D Printed Hand [11]

Figure 14 After assembling all the parts of the hand

4 Algorithms and Their Detailed Analysis

4.1 Algorithm of the Arduino Code

Initialization:

  - Set up the system parameters including the header files, sampling rate, baud rate, and pin configurations.
  - Initialize the communication interfaces (e.g., Serial) for monitoring and debugging purposes.

Setup:

  - Attach the servo motors to their respective pins and set their initial positions.
  - Define the WritePin
  - Configure the EMG sensor input pin and any auxiliary pins required for system operation.
  - Define the threshold voltage (different for each person)

Main Loop:

  - Check WritePin is High or Low

If High, Rotate the thumb, index, and middle finger as such it can hold a pen for writing purposes

If Low, Continue to the next steps

  - Continuously sample the EMG signal at the defined sampling rate.
  - Apply a band-pass Butterworth IIR digital filter to the raw EMG signal to extract relevant muscle activity within the desired frequency range.
  - Compute the EMG envelope using an envelope detection algorithm to estimate the magnitude of muscle activation.

Gesture Recognition:

  - Compare the normalized envelope value with a predefined threshold to determine muscle activation and gesture recognition.
  - Implement a hysteresis mechanism to prevent rapid toggling of the hand due to noise or minor fluctuations in muscle activity.
  - Define specific thresholds for opening and closing gestures based on individual user characteristics and preferences.

Servo Control:

  - Based on the detected gesture:
    - If the muscle activation exceeds the closing threshold:
      - Close the hand by rotating the servo motors to the predefined closed position.
    - If the muscle activation falls below the opening threshold:
      - Open the hand by rotating the servo motors to the predefined open position.
  - Implement a gesture delay to prevent rapid and unintended toggling of the claw in response to minor fluctuations in muscle activity. [1]

4.2 Algorithm for Envelope Detection-

1. Subtract the previous EMG signal value from the sum.
2. Add the absolute value of the current EMG signal to the sum.
3. Store the absolute value of the current EMG signal in the circular buffer at the current index.
4. Update the data index to point to the next position in the circular buffer, wrapping around to the beginning if necessary.
5. Compute the average of the EMG signal values in the circular buffer by dividing the sum by the buffer size.
6. Multiply the average by 2 to scale the envelope signal.
7. Return the computed envelope signal.

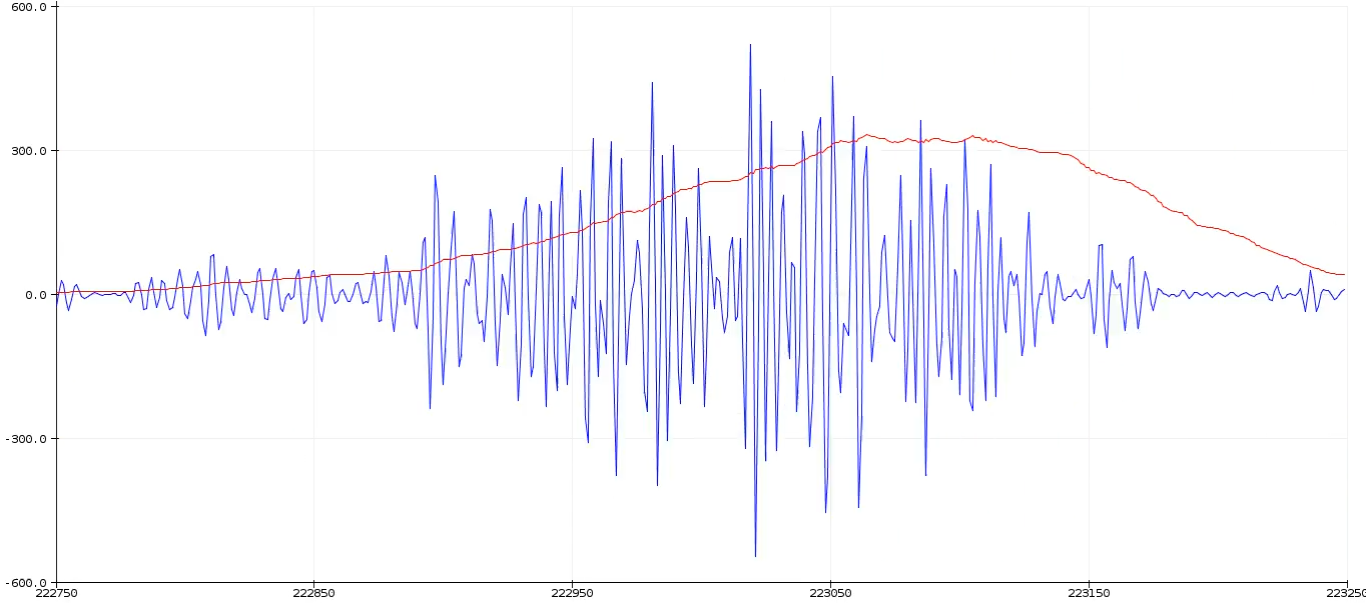
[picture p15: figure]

Figure 15 EMG Signal After Filter with The Detected Envelope [9]

4.3 Algorithm of EMG Band Pass Filter

Algorithm for the Band-Pass Butterworth IIR digital filter:

1. Initialization:
  - Initialize the state variables z1 and z2 for each filter section to zero.
2. Filtering Process:
  - For each input sample:
    - For each filter section:
      - Calculate the intermediate variable x using the difference equation of a second-order IIR filter.
      - Update the output using the calculated x value and the previous state variables.
      - Update the state variables z1 and z2 for the next iteration.
3. Output:
  - Return the filtered output.

Here's a breakdown of the steps within the filtering process:

- For each filter section:
  1. Calculate the intermediate variable x using the difference equation:

x = input - a1 * z1 - a2 * z2

where input is the current input sample, z1, and z2 are the previous state variables, and a1 and a2 are the filter coefficients.

  2. Update the output using the calculated x value and the previous state variables:

output = b0 * x + b1 * z1 + b2 * z2

where b0, b1, and b2 are the filter coefficients for the output.

  3. Update the state variables z1 and z2 for the next iteration:

z2 = z1 z1 = x

Repeating these steps for each input sample, obtained the filtered output of the Band-Pass Butterworth IIR digital filter. [1] [5] [6]

4.4 General Difference Equation of Band-Pass Butterworth IIR digital filter

The code implements a Band-Pass Butterworth IIR digital filter using second-order sections (biquads). Each biquad represents a second-order IIR filter section. Let's break down the mathematical expression for each biquad.

The general difference equation for a second-order IIR filter is:

y[n]=b0x[n]+b1x[n−1]+b2x[n−2]−a1y[n−1]−a2y[n−2]

Where:

- y[n] is the output at time n
- x[n] is the input at time n
- x[n−1] and x[n−2] are the previous input samples
- y[n−1] and y[n−2] are the previous output samples
- b0,b1,b2 are the feedforward (numerator) coefficients
- a1,a2 are the feedback (denominator) coefficients

Let's express each biquad in the code as difference equations:

First Biquad:

z1_1[n] = x[n] - 0.05159732 * z1_1[n-1] - 0.36347401 * z2_1[n-1] z2_1[n] = z1_1[n-1] y_1[n] = 0.01856301 * z1_1[n] + 0.03712602 * z2_1[n] + 0.01856301 * z2_1[n-1]

Second Biquad:

z1_2[n] = y_1[n] - (-0.53945795 * z1_2[n-1] - 0.39764934 * z2_2[n-1]) z2_2[n] = z1_2[n-1] y_2[n] = 1.00000000 * z1_2[n] - 2.00000000 * z1_2[n-1] + 1.00000000 * z2_2[n-1]

Third Biquad:

z1_3[n] = y_2[n] - (0.47319594 * z1_3[n-1] - 0.70744137 * z2_3[n-1]) z2_3[n] = z1_3[n-1] y_3[n] = 1.00000000 * z1_3[n] + 2.00000000 * z1_3[n-1] + 1.00000000 * z2_3[n-1]

Fourth Biquad:

z1_4[n] = y_3[n] - (-1.00211112 * z1_4[n-1] - 0.74520226 * z2_4[n-1]) z2_4[n] = z1_4[n-1] y_4[n] = 1.00000000 * z1_4[n] - 2.00000000 * z1_4[n-1] + 1.00000000 * z2_4[n-1]

Where:

- z1i[n] and z2i[n] are the state variables for the i-th biquad at time n
- x[n] is the input at time n
- yi[n] is the output of the i-th biquad at time n

This set of equations describes the mathematical expression for the given Band-Pass Butterworth IIR digital filter implemented in the provided code. Each biquad contributes to the overall filter response, and the output of one biquad serves as the input to the next biquad in the chain.[5] [6] [7][8]

4.5 Simulation of BPF in MATLAB

Here we have simulated the Band-Pass Butterworth IIR digital filter in MATLAB. First we have shown the unfiltered EMG signal acquired from the hand which consists of different frequencies(45Hz, 60Hz, 90Hz, 100Hz and 160Hz) and noise.

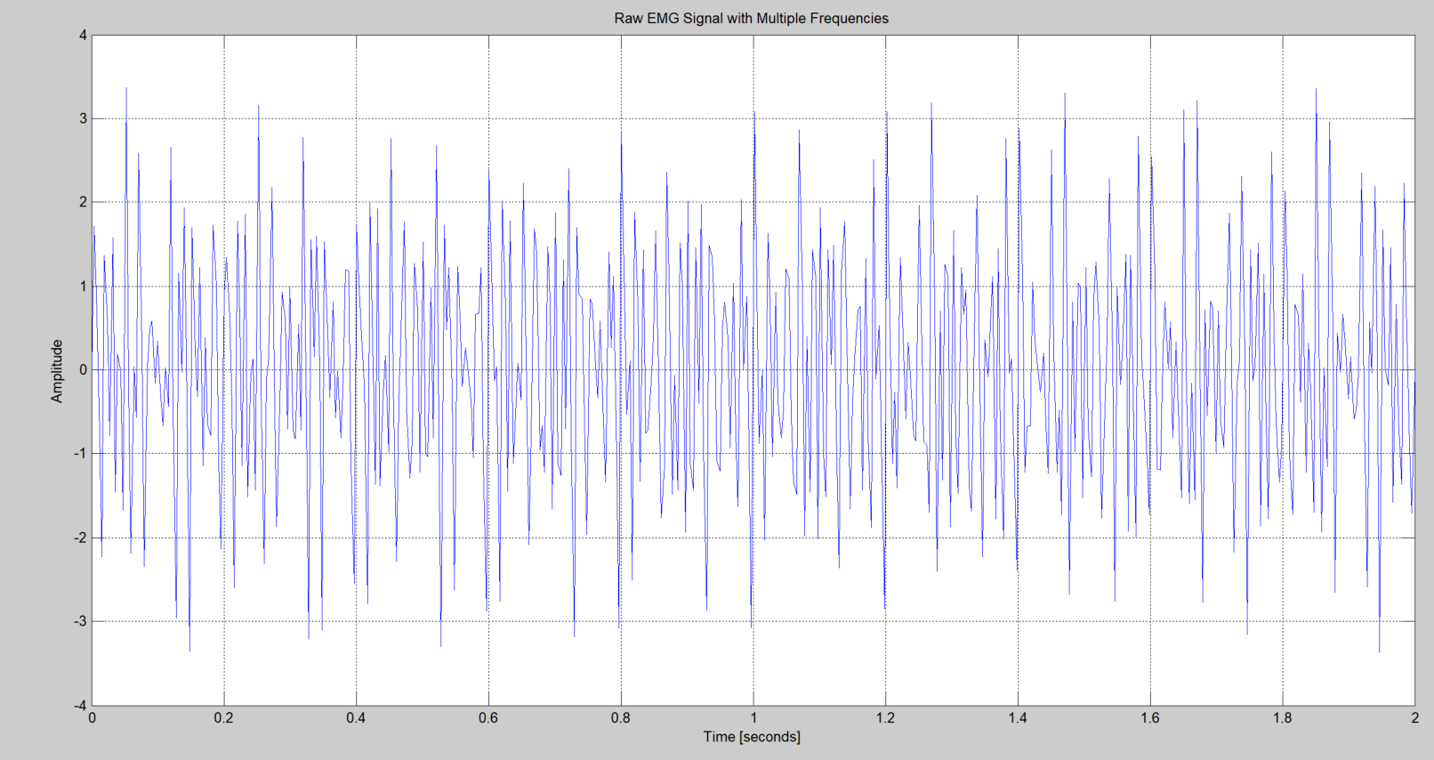
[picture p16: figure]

Figure 16 Raw EMG signal with multiple frequencies of 45Hz, 60Hz, 90Hz, 100Hz and 160Hz [5][6] [7][8]

And here we have shown the EMG signal after passing through the Band-Pass Butterworth IIR digital filter.

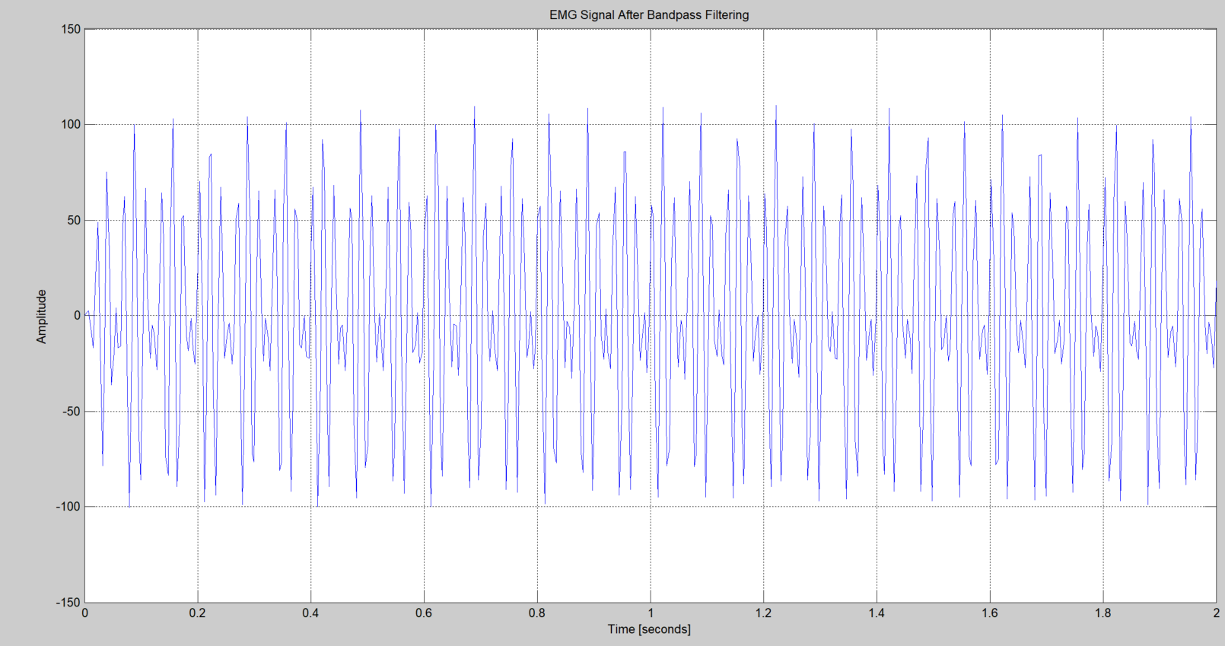
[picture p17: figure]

Figure 17 Filtered EMG Signal after Band Pass Filter consisting of frequencies 90Hz and 100Hz [5][6][7][8]

And this is the frequency response of the Band-Pass Butterworth IIR digital filter with -3db point which has a sampling rate: 500.0 Hz, cutoff frequency: [74.5, 149.5] Hz[5][6] [7][8]

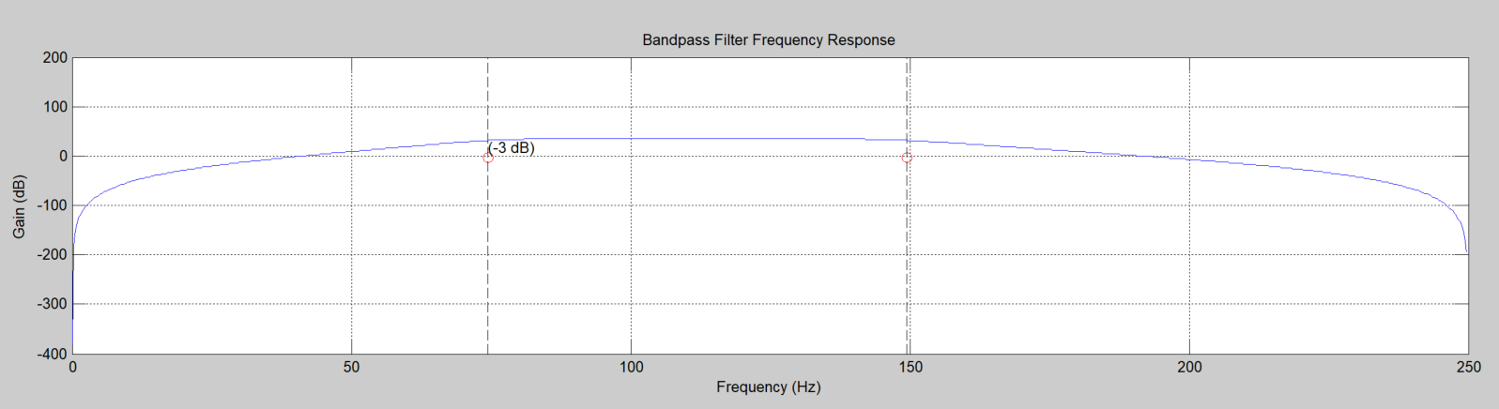
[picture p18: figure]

Figure 18 Frequency response of the Band-Pass Butterworth IIR digital filter with -3db point [5][6] [7][8]

5. Testing and Results

We tested the prosthetic hand with 10 people who have healthy hands and we got these accurate results. We tested 3 things here first how accurately it can grab an object then how accurately it can close and open the hand.

To have better gripping capability we used hot glue to have a better gripping capability in the most probable contact points when trying to grab any object.

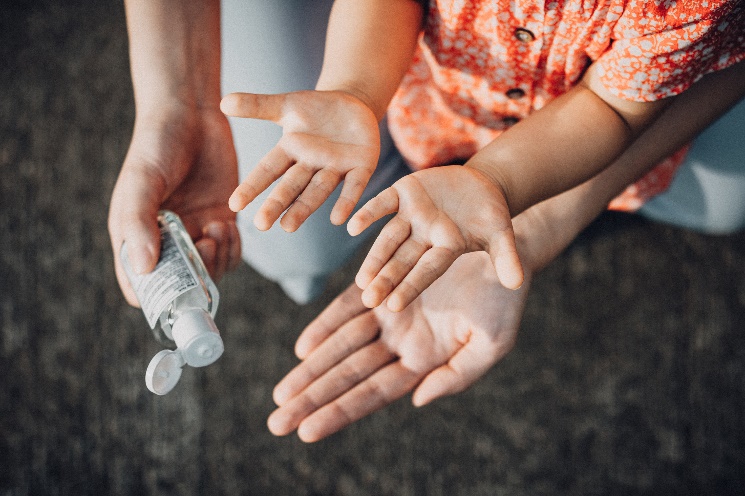
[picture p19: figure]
Parent sanitizing child's hand

Here are some images that shows how the prosthetic hand looks when at rest and flexed.

Figure 19 Hand at Rest (Open) Position

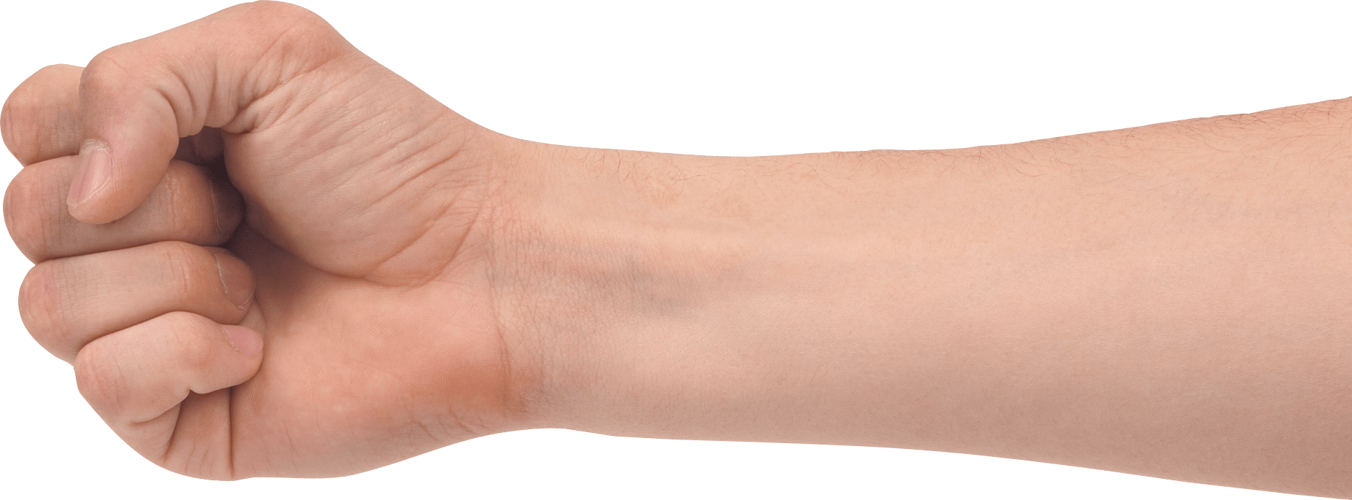
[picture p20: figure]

Figure 20 Hand at Flexed (Close) Position

To test the accuracy of grabbing any object we have used a round object and a cylindrical object as shown in the Figure 20 and Figure 21.

Figure 21 Grabbing one Cylindrical Object

Figure 22 Grabbing one round object

Now here are the results that we got after testing it on 10 people with heathy hands.

Figure 23 Accuracy of Grabbing Any Object With the Prosthetic Hand

Figure 24 Accuracy of Closing and Opening the Prosthetic Hand

6. Conclusion

References

1. GitHub - upsidedownlabs/Muscle-BioAmp-Candy: A candy size ElectroMyoGraphy (EMG) sensor for precise muscle bio-potential signals recording. (n.d.). GitHub. https://github.com/upsidedownlabs/Muscle-BioAmp-Candy

2. Arduino Nano - Soldered (Without Cable). (n.d.). QuartzComponents. https://quartzcomponents.com/products/arduino-nano-v3-0-soldered-without-cable?_pos=2&_sid=2bf3b65a9&_ss=r

3. SG90 Servo Motor Datasheet. (n.d.). https://components101.com/. Retrieved March 24, 2024, from https://components101.com/sites/default/files/component_datasheet/SG90%20Servo%20Motor%20Datasheet.pdf

4. Reconnect Marvel Spiderman 10000mAh PowerBank, Li-Po battery, 1 USBB output port, Micro USB & Type C dual input, BIS approved, Mobile Accessories- DPB102 SM Online at Best Prices in India - JioMart. (n.d.). JioMart. https://www.jiomart.com/p/electronics/reconnect-marvel-spiderman-10000mah-powerbank-li-po-battery-1-usbb-output-port-micro-usb-type-c-dual-input-bis-approved-mobile-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

5. scipy.signal.butter — SciPy v1.12.0 Manual. (n.d.). https://docs.scipy.org/doc/scipy/reference/generated/scipy.signal.butter.html

6. Iyer, S. V. (2020, November 30). Digital Filter Design using Python for Power Engineering Applications. Springer Nature. http://books.google.ie/books?id=jx8MEAAAQBAJ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

7. Verma, N. K., & Ghosh, A. K. (2018, July 31). Computational Intelligence: Theories, Applications and Future Directions - Volume I. Springer. http://books.google.ie/books?id=i_pmDwAAQBAJ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

8. Digital filter. (2023, December 11). Wikipedia. https://en.wikipedia.org/wiki/Digital_filter#Direct_form_II

9. Garg, S., Rathi, K., & Bansal, A. K. (2023, April 1). Development of 3D Printed Bionic Arm Controlled by EMG Sensor. SKIT Research Journal, 13(1), 13–18. https://doi.org/10.47904/ijskit.13.1.2023.13-18

10. Gao, G., Xu, F., Xu, J., & Liu, Z. (2022, October 10). Study of Material Color Influences on Mechanical Characteristics of Fused Deposition Modeling Parts. Materials, 15(19), 7039. https://doi.org/10.3390/ma15197039

11. Hsueh, M. H., Lai, C. J., Wang, S. H., Zeng, Y. S., Hsieh, C. H., Pan, C. Y., & Huang, W. C. (2021, May 27). Effect of Printing Parameters on the Thermal and Mechanical Properties of 3D-Printed PLA and PETG, Using Fused Deposition Modeling. Polymers, 13(11), 1758. https://doi.org/10.3390/polym13111758

12. Sakib, N., & Islam, M.K. (2019). Design and Implementation of an EMG Controlled 3D Printed Prosthetic Arm. 2019 IEEE International Conference on Biomedical Engineering, Computer and Information Technology for Health (BECITHCON), 85-88.

13. What is a Servo Motor? - Understanding the basics of Servo Motor Working. (n.d.). https://circuitdigest.com/article/servo-motor-working-and-basics

14. Muscle BioAmp Band (EMG Band) | Upside Down Labs Store. (2024, March 18). Upside Down Labs Store. https://store.upsidedownlabs.tech/product/muscle-bioamp-band/

15. (2021). EMG sensor based control strategy for hand function movements using 3D prosthetic hand . Journal of Cardiovascular Disease Research, 12(03), Article 0975–3583, 0976–2833. https://jcdronline.org/admin/Uploads/Files/624418536e9b14.69166253.pdf

16. Jun-Uk Chu, Member, IEEE, Inhyuk Moon,” A Supervised Feature-Projection-Based Real-Time EMG Pattern Recognition for Multifunction Myoelectric Hand Control“, IEEE/ASME Transactions on Mechatronics, vol. 12, no. 3, June 2007, p. 282-290

17. A Report on Amputees in India | O&P Virtual Library. (n.d.). https://www.oandplibrary.org/op/1986_01_016.asp

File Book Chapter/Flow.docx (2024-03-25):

YES NO YES NO

Do Nothing

Open The Servo Motors, Set flag = 0

Close The Servo Motors, Set flag = 1

Flag = 1?

EMG envelope> EMG Threshold

Process the EMG signal in Arduino Nano

Process the EMG signal in Muscle BioAmp Candy

Get the EMG signal from forearm

Start

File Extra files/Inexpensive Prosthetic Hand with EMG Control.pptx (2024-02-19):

## Inexpensive Prosthetic Hand with EMG Control

Unique ID: SUP-021
Team Name: Tech NovaCorps

## Introduction

- Developing an Inexpensive Prosthetic Hand
- EMG Signal Acquisition from Flexor Carpi Ulnaris Muscle (FCU) or Ulnar Nerve
- Utilizing Muscle BioAmp Candy from Upside Down Labs

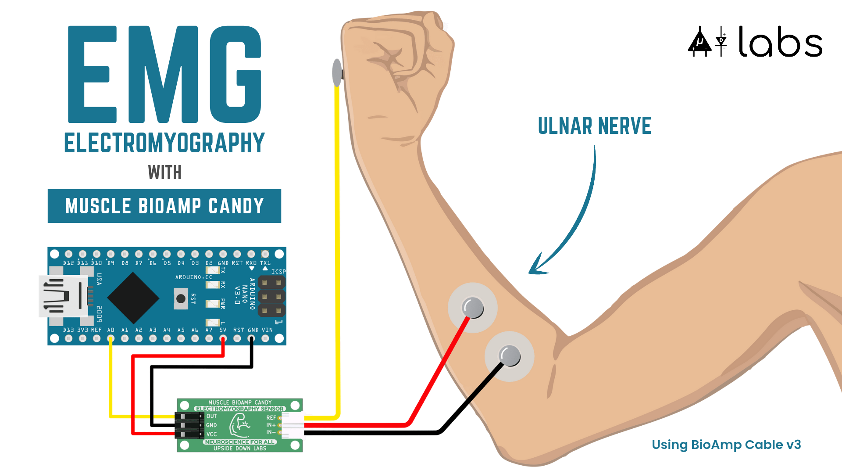
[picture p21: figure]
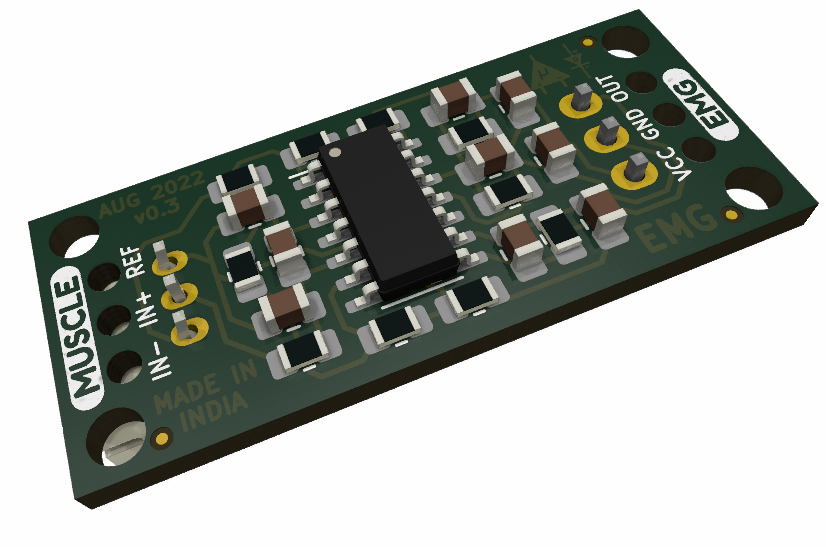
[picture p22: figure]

## Technology Overview

- Muscle BioAmp Candy
  - Compact EMG Sensor
  - Fixed Gain (x2420)
  - Bandpass Filter (72 – 720Hz)
- Arduino Nano Microcontroller
  - Signal Processing
  - Servo Controlling Using PWM Signals

## Components Used

- Muscle BioAmp Candy
- Arduino Nano Microcontroller
- 3D Printed Prosthetic Hand
- Servo Motors(5)
- Overall System Cost Breakdown

Component Name | Price in Rupees
Muscle BioAmp Candy | 700
Arduino Nano Microcontroller | 250
3D Printed Prosthetic Hand Components | 1500
Servo Motors(5) | 510
Total | 2960

## Cost Comparison

- Market Alternatives Cost
  - Range: 5,000 USD to 8,000 USD
(415K-664K INR)
- Project Cost
  - Total: 3,000 rupees or 37 USD
  - Emphasizing Cost-Effectiveness

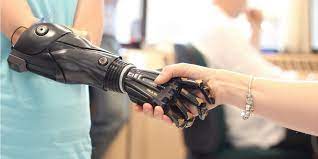
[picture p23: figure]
Open Bionics: Turning disabilities into superpowers | by Shraddha Singh | Medium
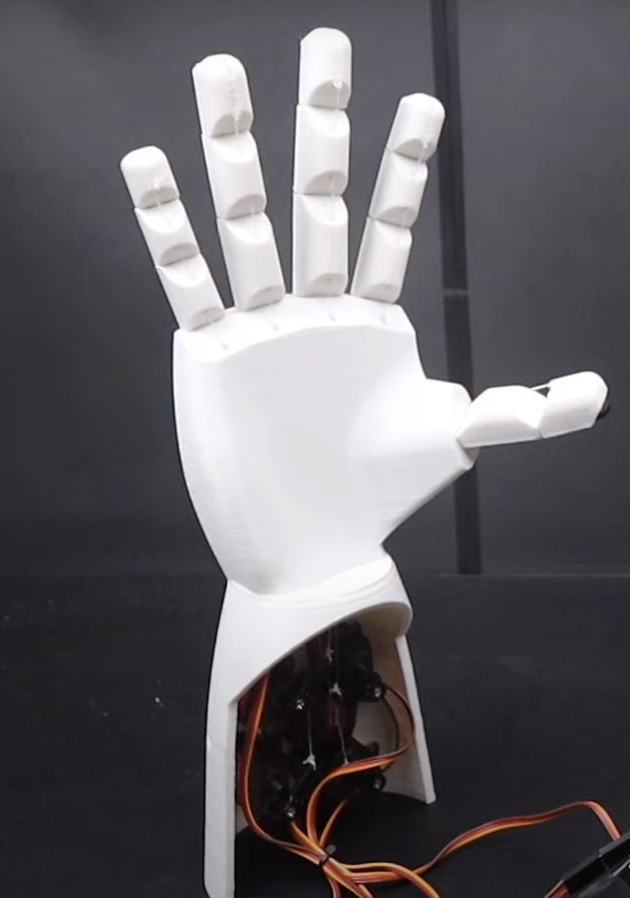
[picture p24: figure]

## What is EMG?

- The EMG signal is generated by the electrical activity of the muscle fibers active during a contraction.
- The signal sources are the depolarizing and repolarizing zones of the muscle fibers.

## Muscle BioAmp Candy

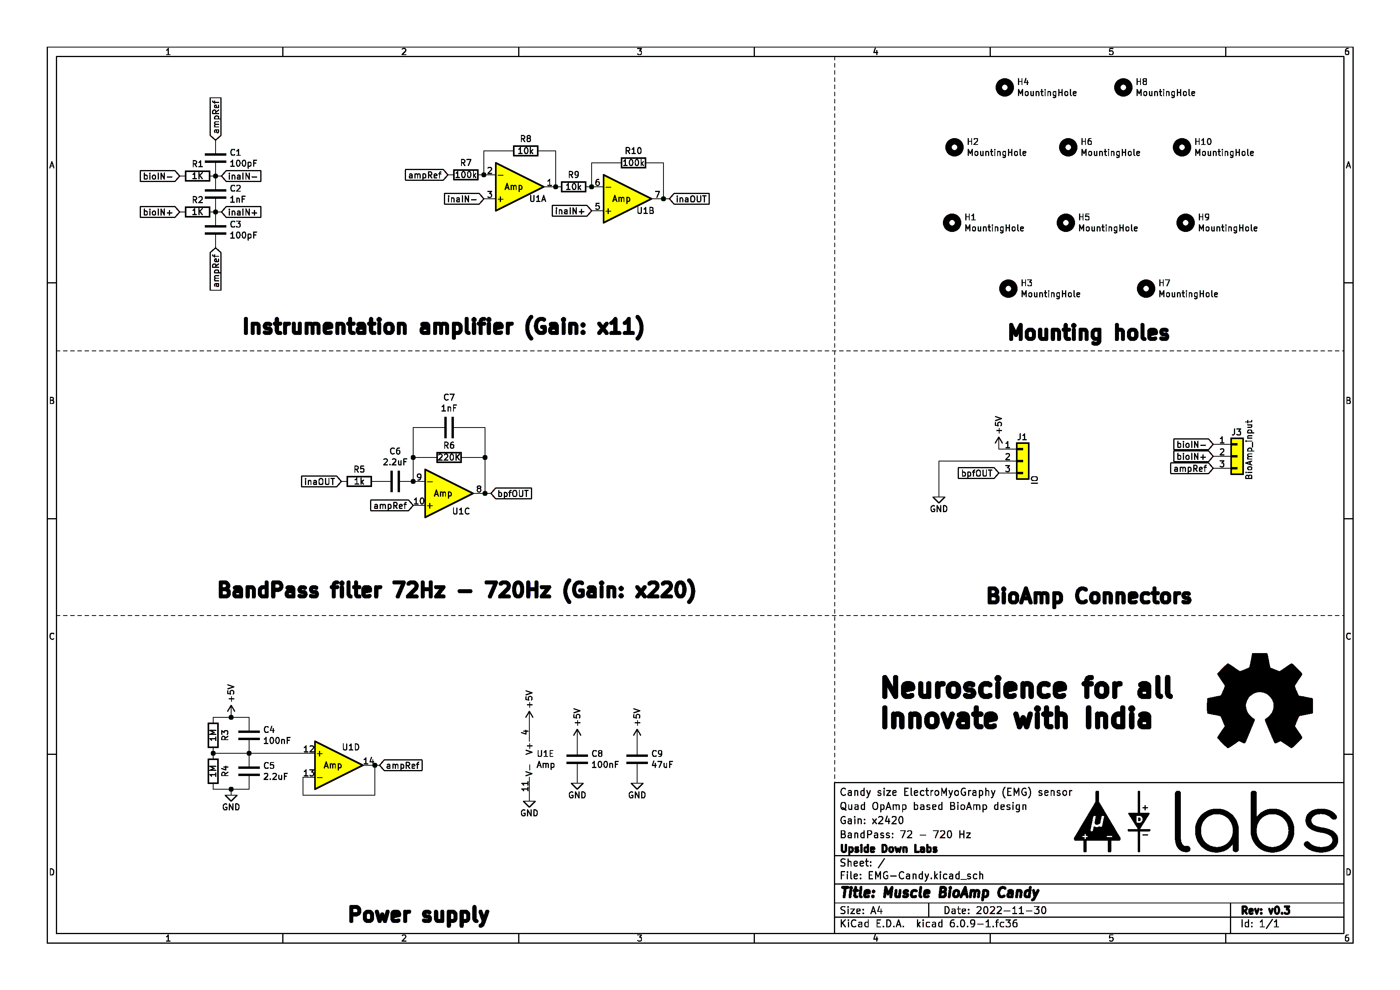
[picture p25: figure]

- Band-Pass Butterworth IIR digital filter(72-720Hz)
- Sampling rate: 500.0 Hz,
- Filter is order 4, implemented as second-order sections (biquads).

## Signal Processing

- Role of Muscle BioAmp Candy
  - Instrumentation Amplifier
  - Non Inverting Amplifier
  - Bandpass Filter (72 – 720Hz)
- Role of Arduino Nano
  - Works as ADC for converting the
analog signals to digital signals
  - Envelope Detection


## Conclusion

- Economic Viability and Affordability
- Bridging the Gap in Prosthetic Technology
- Future Potential and Development

## References

- https://docs.scipy.org/doc/scipy/reference/generated/scipy.signal.butter.html
- https://courses.ideate.cmu.edu/16-223/f2020/Arduino/FilterDemos/filter_gen.py
- https://github.com/upsidedownlabs

## Team Members

- Rajdeep Saha (Electronics and Communication Engineering)
- Abhijit Biswas (Electronics and Communication Engineering)
- Saradwat Sen (Electronics and Communication Engineering)
- Sayani Dhali (Electronics and Communication Engineering)

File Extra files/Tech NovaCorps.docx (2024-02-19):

Unique id: SUP-021

Team Name: Tech NovaCorps

Inexpensive Prosthetic Hand based on EMG Signal Acquired from the Hand of The Amputee

This project presents an inexpensive prosthetic hand controlled by electromyographic (EMG) signals acquired from the upper arm muscles of amputees. Employing the Muscle BioAmp Candy provided by Upside Down Labs, which consists of a compact muscle sensor with a bandpass filter (72 – 720Hz) and fixed gain (x2420), the system ensures precise EMG sensing. The Arduino Nano microcontroller acts as a brain for signal processing, enhancing the prosthetic hand's responsiveness. Remarkably cost-effective, the overall system along with the Muscle BioAmp Candy costs around only 3,000 rupees or 37 USD significantly reducing expenses compared to market alternatives, which can cost from 5,000 USD upto 8,000 USD (415K-664K INR). This project not only showcases advancements in EMG-based prosthetics but also emphasizes the economic viability of integrating cutting-edge technologies for improved accessibility and affordability.

Participants Name:

1) Rajdeep Saha, Electronics and Communication Engineering

2) Abhijit Biswas, Electronics and Communication Engineering

3) Saradwat Sen, Electronics and Communication Engineering

4) Sayani Dhali, Electronics and Communication Engineering

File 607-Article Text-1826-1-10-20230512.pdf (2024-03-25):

SKIT Research Journal | Vol 13 Issue 1 (2023) | ISSN 2278-2508 (P) 2454-9673(O)

# Development of 3D Printed Bionic Arm Controlled by EMG Sensor

Sudesh Garg¹

, Kiran Rathi²

, Amit Kr. Bansal¹
1Department of Mechanical Engineering, Swami Keshvanand Institute of Technology, Management & Gramothan, Jaipur -302017 (INDIA) 2Department of Electronics & Communicaiton Engineering, Swami Keshvanand Institute of Technology, Management & Gramothan, Jaipur -302017 (INDIA)
Email: sudesh.garg@skit.ac.in, kiran.rathi@skit.ac.in
Received 31.01.2023 received in revised form 01.02.2023, accepted 13.03.2023
DOI: https://dx.doi.org/10.47904/IJSKIT.13.1.2023.13-18

Abstract- Man is a one-of-a-kind creation that only God could have made. They are an invaluable asset to the human body, with each component serving a purpose that is distinct from the others. Because of the significant impact that they have on a person's day-to-day and professional activities, a person's fingers, lower arm, and forearm are the body parts that should be preserved following an amputation the most. The primary goal of this bionic arm is to regain fundamental control of the hand at a price that will enable amputees with limited financial resources to purchase a bionic arm. This technology is utilized in the production of many of the artificial arms that are currently available for purchase around the world; however, these arms come at a very high cost. This study demonstrates the design, manufacturing, and functioning of a 3-D printed prosthetic hand that employs an electromyography (EMG) sensor in order to imitate the fundamental motions that are carried out by human hands (holding an object, lifting an object, shutting and opening fingers).

Keywords- Bionic Arm, Electromyography (EMG), Mesh, Stress, Deformation, Polylactide (PLA)

### 1. INTRODUCTION

Human is a unique creature created by God. For human, their body is like a valuable asset of which each part has a different importance. Just as a robotic
platform | requires | actuators, | sensors | and
microcontrollers, similarly the human body requires arms, legs and brain. When a person is amputated due to some reason, an accident or birth itself, such as a hand, leg, finger or claw, then the person's ability to do the work of daily life is reduced or completely lost and along with this in many cases it makes him dependent on others. But due to the excellence of science, some artificial organs have been developed to make life a little easier for such people.
The most valuable body part in an amputated human is its fingers, lower arm and forearm which affects its daily life as well as professional life [1]. A human hand amputation has a severe detrimental effect on a person's professionalism and disqualifies them from participating in a number of sports and jobs. At present, many such robotic arms or bionic hands are available, which try to meet the needs of disabled people in this way. A bionic arm is a mechatronically designed device that works like a normal human arm in certain limits and is a boon for amputees. Different types of technology, materials and sensors are used to make this artificial hand, but due to not being budget friendly and not having fast availability, these hands are not affordable for poor and middleclass amputees. Over the past twenty years, major advances have been made in the creation of revolutionary prosthetic hands and terminal devices that utilize advantage of the most rapid technological advancements, resulting in the construction of more dexterous hand devices [2].
Ahmed.et al. [3] fabricated a prosthetic hand, in which servo motor was connected along with the flex sensor which develop an affordable five degree of freedom (DOF) and two joints in each finger. Aayush Kumar et al. [4] created a 3-D printed robotic arm using PLA material along with muscle sensors that detect changes in strain and act according to the bionic hand. Dunai L. et al. [5] created a 3D printed robotic arm that simulated hand touch pressure using the FSR sensor. Samara M. et al. [6] told about, prosthetic hand and fingers, which were modeled using (Petg-CR) material, are subjected to stress and strain analysis and determine the impact of various
load | circumstances | on | the | intended | hand.
Wattanasiri. et al. [7] proposed a prosthetic hand developed in SIM-Mechanics environment, which has different kind of patterns of grip and a tactile switch was used on the back side of the artificial hand. This switch was used to select desired grip on the hand by pressing it.
Research work presented here, explains the design, fabrication and operation of a 3-D printed prosthetic hand which uses EMG sensor for imitating the basic movement done by human hands with lower arm and closing, opening and turning of fingers like holding an object, lifting the object. The main advantages of this hand are that the it is portable, inexpensive and lighter in weight compared to the modern bionic arm available.

### 2. DESIGN AND DEVELOPMENT

Different types of technology, materials and sensors are used to make this artificial hand. According to the characteristics of various bionic arms, in this current arm system design we uses the following modules and components:

Table: 1 Characteristic of Some Popular Bionic Arms in India [8, 9, 10, 11, 12]
S.N. | 1 | 2 | 3 | 4 | 5
Producer | Otto –Bock | Touch Bionics | Robo Bionic Hand | Deka Bionic Arm | Open Bionics Labs
Battery Used | Lithium- ion | Lithium Polymer | lithium-ion | Lithium- ion | Lithium Polymer
Weight (Approx.) | 500 g | 600 g | 800 g | 1.3 kg | 950 g
Grips/ hand positions | 14 | 8 | 6 | 6 | 9
Feed Back-System | No | No | Yes | No | No
Sensor Used | EMG | EMG | MMG | Foot Control, Myo-electrode | EMG
Operating Voltage | 12 Volt | 7.5 Volt | 12 Volt | 9 Volt | 12 Volt

Table: 2 Components used in Robotic Arm

SN | Main-Component | Figure | Specification
1 | Arduino Nano Board | | Microchip ATmega328P 5 Volts 8 Analog input pins
2 | Servomotor | | 60g,Metallic Gear 1ms Pulse 6 Volt

Battery; 9 Volt,82g Model: HLW 6F22M

4 | EMG - Sensor | | Supported with Arduino, 30g
5 | I. PC 3D PRINTER FILAMENT | • Strength :61.5MPa • Melting Temperature: >155°C •


Fig. 1: Block Diagram of the Proposed System

### 3. FABRICATION OF BIONIC ARM

Material Used
PLA is a well-known name in the world of 3D printing, a material most commonly used to make 3D printed components. PLA material is popular because it is easily available, environment friendly and cheap. PLA is a biodegradable material obtained from food crops such as sugarcane, corn and jowar. Some important features of PLA are as follows:

Table: 3 Features of PLA
S.N. | Property | Value
1 | Melting Point | Low
2 | Low Thermal Expansion | Low
3 | Layer adhesion | Good
4 | Heat Resistance | High
5 | Strength | High
6 | Dimensional accuracy | High

3D printing
3D printing is a manufacturing process that creates a physical object from a digital model file. The technology works by adding layer upon layer of material to build up a complete object [13]. In this current work we use the Max200-3D printer with
Ultimaker | CURA | software | for | making | the
mechanical components of the robotic arm. Some important features of 3D Printer are as follows:

Table: 4 Features of 3D Printer [14]
S.N. | Property | Value
1 | Model Name/Number | Max-200
2 | Material | Polyamide (PLA)
3 | Software / Supporting | Ultimaker CURA/ STL
4 | Technology | FDM
5 | Connectivity | USB
6 | Build Plate Temperature | 600
7 | Total Time for Printing | 35 Hrs. Approx.


Fig. 2 (a), (b), (c) and (d): 3D Printing Under Process [Source: SKIT, M &G College, e-Yantra Lab]


Fig. 3: Fabricated 3D Printed Parts of Bionic Arm

### 4. ASSEMBLY OF ROBOTIC ARM

In this bionic arm all the mechanical parts made from 3D printing are integrated with the electrical components. The bionic arm needs to be made cheaper, lighter and accessible than the bionic arm already available in the market. So all the electric components were selected based on the obtained output and requirements. At first all parts of fingers are connected to one another with the help of nylon or fishing wire with palm of the bionic hand.
All the finger parts connected through the servo motor for desired action. Servo motor and EMG sensor are then connected to the Arduino-Nano. When we stretch or move our muscles, the EMG sensor detects this change and sends signal to Arduino.


(a) (b)
Fig. 4 Assembly of Fingers Parts, Palm, Lower Arm


Fig. 5: Assembly of Servo Motors, Arduino, EMG Sensor, Battery and Circuitry Board


Fig. 6: Whole Assembly of Bionic Arm Components

### 4. RESULT

The system suggested in this work is designed with a five-finger structure, but each finger is modularized, allowing it to be designed with end-effectors of varied shapes based on the palm shape. Actually, as soon as we mentally decide to move or extend our hand or fingers, our brain sends out a signal that travels through the neural system to the nerves in our hand. When we stretch or move our muscles, the EMG sensor detects this change when it is placed on the skin as seen in figure 7. The EMG detects the target muscle group's contraction and relaxation, and a potential is created.

Our Muscle Sensors are designed to be used directly with a microcontroller. Therefore, our sensors do not output a RAW EMG signal but rather an amplified, rectified, and smoothed signal that will work well with a microcontroller’s analog to digital converter (ADC). Because it is programmed to be capable of reading the signal which is received from the EMG, the Arduino can easily read the signal received on the analog pin. By comparing the signal with the predefined value in Arduino, the signal is sent to the motors (actuators) and the desired action of the finger is executed. To evaluate the item gripping capabilities of the bionic arm, as depicted in Figure 10, we have identified the six grasp kinds listed below. The precision grab is a test of manual dexterity and sensibility.

Program/ Source Code


Fig. 7: Opening and Closing of Fingers in Prototype


Fig.9: Flow Chart of Action of Bionic Arm with EMG Input


Fig. 10: The grasp taxonomy [15]

### 5. CONCLUSION

The major goal of this work was to create a bionic arm that is affordable and durable along with easily accessible to everyone. Both the goals of this project were achieved and new directions for future study in this area have been developed.
1. The bionic arm's fingers were capable of performing out daily tasks with good grip.
2. The model for the bionic arm and its fingers help support
3. The fabricated bionic arm is more readily available, lighter, and less expensive than the bionic arm that is currently on the market. Although bionic arm implants provide many advantages, they also pose serious health hazards. Technology for bionic arms is constantly developing, with a focus on better control systems, richer sensory feedback, and quicker response times. These gadgets are still sometimes quite delicate.

### 6. REFERENCES

[1]. Cotton, D. P. J., et al. “Control Strategies for a Multiple Degree of Freedom Prosthetic Hand.” Measurement and Control, vol. 40, no. 1, SAGE Publications, Feb. 2007, pp.
24–27. | Crossref,
https://doi.org/10.1177/002029400704000108
[2]. .Geizans Reinis et al. “Developing 3D Printed Prosthetic Hand Model Controlled by EMG Signal from Forearm”May, 2018, Metropolia University of Applied Sciences,Volume 01,Issue 01.
[3]. Sahla Yoosuf Husain Ahmed, 2020, Bionic Hand, International Journal Of Engineering Research & Technology (IJERT) NSDARM – 2020 (Volume 8 – Issue 04), doi : 10.17577/IJERTCONV8IS04004
[4]. Kumar Ayush et al. “Bionic Arm Using Muscle Sensor” July, 2022, International Journal for Research in Applied Science & Engineering Technology (IJRASET), Volume 10, Issue VII, ISSN: 2321-9653.
[5]. Dunai L, Novak M, García Espert C. Human Hand Anatomy-Based Prosthetic Hand. Sensors (Basel). 2020 Dec 28;21(1):137. doi: 10.3390/s21010137.
[6]. Samara Munaem Naeem, Majid Habeeb, Stress and Strain Analysis for the Prosthetic Hand Design Actuated, Journal of Mechanical Engineering Research and Developments ISSN: 1024-1752 CODEN: JERDFO Vol. 44, No. 9, pp. 426-435 Published Year 2021
[7]. Wattanasiri P, Tangpornprasert P, Virulsri C. Design of Multi-Grip Patterns Prosthetic Hand With Single Actuator. IEEE Trans Neural Syst Rehabil Eng. 2018
Jun;26(6):1188-1198. | doi:
10.1109/TNSRE.2018.2829152. PMID: 29877843.

[8]. “Welcome to Ottobock.” Welcome to Ottobock, www.ottobock.com/en-us/Home. Accessed 27 Nov. 2022.
[9]. “Prosthetic Hands and Digits for Upper Limb Difference. Ossur.com.” Prosthetic Hands & Digits for Upper Limb
Difference. | Ossur.com, | www.ossur.com/en-
in/prosthetics/hands. Accessed 27 Nov. 2022.
[10]. “Robo Bionics - Made in India Bionics - Prosthetics for the Common Man.” Robo Bionics, www.robobionics.in. Accessed 27 Nov. 2022.
[11]. “DEKA | Bionic | Arm.” | Wevolver,
www.wevolver.com/specs/deka.bionic.arm. Accessed 29 Nov. 2022.
[12]. “Open | Bionics | Labs.” | Open | Bionics,
openbionicslabs.com. Accessed 30 Nov. 2022.
[13]. Shahrubudin, N., et al. “An Overview on 3D Printing
Technology: | Technological, | Materials, | and
Applications.” Procedia Manufacturing, vol. 35, Elsevier
BV, | 2019, | pp. | 1286–96. | Crossref,
https://doi.org/10.1016/j.promfg.2019.06.089.
[14]. “UltiMaker Cura: Powerful, Easy-to-use 3D Printing
Software.” | https://ultimaker.com,
ultimaker.com/software/ultimaker-cura. Accessed 5 Jan. 2023.
[15]. Park, Hyeonjun, and Donghan Kim. “An Open-source Anthropomorphic Robot Hand System: HRI Hand.” HardwareX, vol. 7, Elsevier BV, Apr. 2020, p. e00100. Crossref, https://doi.org/10.1016/j.ohx.2020.e00100.

Appendix

Table: 1 Action of BionicArm Pose with respect of Real
Hand
SN | The Real Hand Pose | Action | The Bionic Arm Pose

One Finger Open
Two Finger Open

3 | | All Five Finger Open

Fist (Grasp)

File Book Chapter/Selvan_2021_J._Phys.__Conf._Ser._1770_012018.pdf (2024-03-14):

## Journal of Physics: Conference Series

PAPER • OPEN ACCESS

## Prosthetic Hand Using Emg

To cite this article: Mercy Paul Selvan et al 2021 J. Phys.: Conf. Ser. 1770 012018

View the article online (https://doi.org/10.1088/1742-6596/1770/1/012018) for updates and enhancements.

## You may also like

Sensory feedback by peripheral nerve stimulation improves task performance in individuals with upper limb loss using a myoelectric prosthesis (https://iopscience.iop.org/article/10.1088/1741-2560/13/1/016001)
Matthew Schiefer, Daniel Tan, Steven M Sidek et al.

Prosthetic hand with 2-dimensional motion based EOG signal control (https://iopscience.iop.org/article/10.1088/1757-899X/850/1/012024)
M R Pratomo, B G Irianto, T Triwiyanto et al.

Feedback-aided data acquisition improves myoelectric control of a prosthetic hand (https://iopscience.iop.org/article/10.1088/1741-2552/abbed0) Andrea Gigli, Donato Brusamento, Roberto Meattini et al.


This content was downloaded from IP address 223.29.201.58 on 14/03/2024 at 09:06

Content from this work may be used under the terms of theCreative Commons Attribution 3.0 licence. Any further distribution of this work must maintain attribution to the author(s) and the title of the work, journal citation and DOI.
Published under licence by IOP Publishing Ltd

International Conference on Mathematical Sciences (ICMS 2020)
Journal of Physics: Conference Series | 1770 (2021) 012018

IOP Publishing
doi:10.1088/1742-6596/1770/1/012018

## Prosthetic Hand Using Emg

DR MERCY PAUL SELVAN[1], RISH I RAJ[2], R GOWTHAM SAI[3], DR S. JANCY [4], DR VIJI AMUTHA MARY [5]

[1][4]Asst. professor, Dept. of CSE, Sathyabama Institute of Science and Technology, Chennai, India.

[2][3] UG Student, Dept. of CSE, Sathyabama Institute of Science and Technology, Chennai, India.

[5] Associate Professor, Dept. of CSE., Sathyabama Institute of Science and Technology, Chennai, India.

mercypaulselvan@gmail.com

Abstract. The prosthetic hand is a device used for the amputee to make them capable of doing daily life stuff. Losing upper limbs is not just a physical loss it also affects the way that person sees their life, they start feeling disabled all the time. This event grows and make them disabled mentally or by god if they can handle it even though people will remind them time to time about their disabilities which may lead to suicide or even worse. To join hand to hand and to makes more abled than disabled, we are introducing prosthetic hand at the cheapest price. It's not that this event is the only device in the market but I could say this event is the cheapest one with these many qualities. It could not be very good looking but it could be better than a decent one. Disability does not differentiate by the salary of a person or capability of someone, so this should be affordable to most of them. In the west, we have some country who can make prosthetic at an affordable price but their money and employment are stronger than us. So, a project like this can make a difference. The concept partially fulfilled the goals and targets set at the outset of the project. The initiative originally had four primary goals. The first goal is to create a tool like a prosthetic hand that can help an amputee with hand loss accomplish simple everyday tasks. Because of all the EMG signal calculation of various hand movements performed on a person who does not lose his her hand the system can only partially accomplish this goal.

Keywords— Amputees, prosthetics, EMG, impulse, signals, Arduino. The first section in your paper

### 1. Introduction

The prosthetic hand is an artificial device which is designed for the people with upper limb amputations to come up with some functions of the natural hands. The number of amp utees in the developing countries is significantly greater than in developed countries due to minimum medical facilities and the popularity of illnesses that have been cured in the developed world. Loss of upper limbs has many circumstances not only in the sense of physically but also in social and psychological department. Artificial hands and wrists are used to conduct everyday tasks such as washing, writing and picking various items to mitigate these effects and enable the amputee to return to normal life. There are many commercial prosthetic hands available these days in the market. Such devices range from designer cosmetic hands to split hook, myoelectric hook and hand with body harness power. Out of all the variation in their mechanical structures, control signal types, and power sources, most of them are at thousands of rupees incredibly costly. Even cosmetics, prosthetic made specifically for

Journal of Physics: Conference Series | 1770 (2021) 012018

doi:10.1088/1742-6596/1770/1/012018

aesthetics, although not much expensive, but still they cost lakhs of rupees. Hence, in developing countries, very few amputee’s have prosthetics not because they are pricey, but also due to distribution and maintenance problem. One of its main goal of our project is to develop a lower-cost 3D prosthetic hand printed for amputees. A standard myoelectric hand, where all the EMG surface electrodes on the amputee hand capture myoelectric signals that are manipulated to enable the hand to open and close. In the past decade, advances in 3D printing have made 3D trans-radial prosthetics a cheap substitute. It provides robust features at an inexpensive price. There are many designs these days that vary in capacity and operate quite differently, such as reliability, control mechanism, hand grips, user interfaces, convenience and cost. Every prosthetic hand has strengths and weakness of its own. The main aim of this bachelor's thesis is to create a 3D printed prosthetic hand that can be operated from the forearm using an EMG signal. The prosthetic to replace the missing hand must be attached to the patient's forearm. To monitor the impulse, three electrodes (EMG stickers) that read the EMG signal will be attached in the forearm at different locations. Five distinct DC motors are available to handle every finger's controls, and one servo motor would be to control wrist rotation. To create an adequate prosthetic hand design, it is important to understand the fundamentals of anatomy and physiology of the human hand. Anatomy is structure analysis, and physiology is role analysis. A successful model of the prosthesis could be produced by observing and understanding into the shape and work of the human hand. The human hand can be a fine instrument in many respects. This represents the various degrees of freedom and can work in an interconnected way. With present technology, it is impractical to assume that any of the standard hand's parameters and output requirements may be replicated in a handmade unit. The human hand can be a fine instrument in many respects. This represents the various degrees of freedom and can work in an interconnected way. With existing technologies, it is impractical to assume that any of the standard hand's parameters and output requirements may be replicated in a handmade unit. With these perfect parameters, consensus can be made and a practical prosthetic hand can be built. The main aim of this section is to examine the natural hand's functional capacity and evaluate the most common grasping patterns of the hand from an unlimited range of patterns.

### 2. Literature Survey

This project is all about amputees who have lost their upper limb by accident or god’s act. It is a very ugly that they feel disabled in such a well-educated society. What we are doing for them, absolutely negligible. India is rich in population so we have many amputees who are living life to finish not to enjoy. So, we are here with a project to make our disabled abled. This project is all about making a prosthetic as advanced as it was never been. Let us see how it works. Base Paper: Wearable Mind Thoughts Powered 3D Printed Open Source Arm with Integrated Feedback Sensor System. Address: https://www.researchgate.net/publication/32738 7513 Wearable Mind Thoughts Powered 3D Printed Open Source Arm with Integrated Feedback Sensor System. Related Projects: Building a Helping Hand: The human body is an extraordinary piece of machinery, and our hands are no exception. With some training, they can perform delicate and complex tasks like grabbing pens and tools to create art.
Unfortunately, | we | have | rapidly | growing | demand | for | hand | replacements. | In
https://www.sciencebuddies.org/science-fairprojects/project-ideas/HumBio p042/human-biologyhealtNbuild-prosthetic-hand DIY Prosthetic Hand & Forearm, he uses a previously designed
Robotic | hand | that | is | part | of | an | open-source | robotics | project | called | InMoov.
https://www.instructables.com/id/VoiceControlled-Prosthetic-Hand-Forearm/ Designing a Human Hand: Current prosthetic hands have limited functionality and are expensive. Design of a cost-
effective | anthropomorphic | prosthetic | hand | was | created. | https://web.wpi.edu/Pubs/E-
project/Available/Eproject-042612- 145912/unrestricted/MQP PaulV Complete Fi nal 3.pdf IoT Book: The Internet of Things” by Samuel Greengard, Precision: Principles, Practices, and Solutions for the Internet of Things” by Timothy.

Journal of Physics: Conference Series | 1770 (2021) 012018

doi:10.1088/1742-6596/1770/1/012018

### 3. Algorithm

Step 1 — We must have all the devices used in the project which includes 5 Servo motors 3D Printed hand, two batteries less that 18V, Wires as required, EMG, three EMG Stickers and Arduino.
Step 2 — All the connection should be done properly.
Step 3 — Upload program to the Arduino.
Step 4 — Stick the EMG stickers and give power Supply.
Step 5 — We can see the result after moving our hand.

### 4. Design

Research in 3D printing over the last decade, have made 3D printed prosthetics an inexpensive option. It provides a complex function at an affordable price. In the market, multiple options range very fluctuating in ability and function such as durable, control system, handgrip, amputees’ inputs, comfortable and cost. Each prosthetic has its strength and weakness. The objective of this paper is to design a 3D printed prosthetic hands which can be controlled by EMG signals (impulse) from the forearm. The prosthetic hand will be attached to the patient’s forearm to overcome the lost arm. Three electrode stickers reading the EMG signal will be attached in the residual hand to control the prosthetic hand. Five DC motors are used to control fingers.

Impulse(Signal) from hand using EMG stickers; Prosthetic Hand is ready to move; £ lectromyogra phy (EMG) device to read the impulse; Servo motors will; relieve instruction; from Ar duino; Analog signal will; be transmitted to Arduino.; Arduino will act according to the code using emg data

Fig. 1 Architecture

Thus, the first and main task to be | solved | by performing this research was to design a
device in the form of a prosthetic arm which can be controlled by the amputees. The theme is to let the amputee perform simple daily tasks like holding and releasing objects. Since the prosthetic will be attached to the amputee’s forearm so the structure should be light and the size should be suitable for amputees. Another purpose of this project was to design an affordable prosthetic hand for poor amputees. A prototype prosthetic was created that has basic hand functionality, a durable yet lightweight structure utilizing 3D printing and a control unit, all available at a fair value for money. This article deals with the method of modelling, manufacturing and evaluating radial 3D printed trans prosthetics. The prosthetic hand works by capturing capturing impulse from amputee. This happens by sticking stickers on amputee’s

Journal of Physics: Conference Series | 1770 (2021) 012018

doi:10.1088/1742-6596/1770/1/012018

hand which gives us reading like given in Fig. 3. If a muscle gets a neuromuscular stimulus from the brain, it activates a potential for activity in the muscle cell, it is simply a change in voltage across the cell membrane. Chemical electromyography methods can be used for calculating these voltages on the surface of the skin.


Fig. 2 Connection

I i lie real I X1€ i

SlAr4

FIG. 3 EMG Reading
The electrical pulse measured on the skin surface can have | different | frequencies | based | on
muscle contraction strength. To detect | the | electromyography signals, | the | EMG | sensor | is
mounted at different locations of the forearm. Although the location and direction of the
muscle sensor electrodes has a considerable effect on the | intensity | of | the | signal, | both
theoretical anatomies of the human muscle and scientific studies have carefully | selected | the
positions of the electrodes.
The electrode stickers will be in the centre of the muscle and aligned in the direction of the fibre muscle. Positioning the sensor elsewhere will differ the intensity and efficiency of the signal from the

Journal of Physics: Conference Series | 1770 (2021) 012018

doi:10.1088/1742-6596/1770/1/012018

sensor. The digital representation of electrical impulses from muscles is an EMG signal. Myoelectric refers to muscle electro- signals. If anyone thinks about flexing a muscle their brain sends a neuromuscular or electrical signal to the muscles called an urge. Now the muscles continue to use motor units or bundles of muscle fibres that induces forces behind the muscles. As much as the muscle is flexed, the more motor units are mobilized to induce more muscle energy and the larger the number of motor units, the greater the muscle generates the electrical activity. Any time the impulse arrives from the brain, EMG stickers send it to EMG to reads it and sends it to Arduino.


Fig. 4 EMG SENSOR
Arduino is designed in such a way that the servo motor | is shifted in a certain | direction as
reading crosses the threshold. An SG90 servo motor was selected for finger actuation. This compact and basic motor has been chosen because it can provide all the requisite features such as tiny size, lightweight, built- in gearbox and low price. The SG90 servo motor image is seen in Figure S. The above servomotor still has some drawbacks that had to be changed given the advantages. Initially, it was built for a particular degree of rotation, in this case, this is 180 degrees in all the direction and 90 degrees.


Journal of Physics: Conference Series | 1770 (2021) 012018

doi:10.1088/1742-6596/1770/1/012018

Fig. 5 Prosthetic hand
This trait is induced by the gearbox and potentiometer hardware limit. This servo motors will have continuous continuous rotations and a feedback loop with continuous rotation.


Fig. 6 Servo Motor

Power supply will be given to Arduino which will move servo motors.

### 5. Code

#include <Servo’s> Servo myservo; void setup()

myservo.attach(9); Serial.begin(9600); pinMode(13,OUTPUT);

void loop() (
int x —— analogRead(A0); Serial.println(x);

if(x>——300)(

myservo. write(270); delay(1000);

else( myservo.write(0);
delay(50);
} Serial.println(x);

### 6. Result

Loss of hand can cause many consequences in daily life. Numbers of opportunities is reduced because of hand loss. Hence, Research into producing a prosthetic hand that can be easily operated from the arm by the EMG signal is also a big step towards prosthetics. The prosthetic hand is having 5 servo motors. With this project, it was selected to save time using the open- source

Journal of Physics: Conference Series | 1770 (2021) 012018

doi:10.1088/1742-6596/1770/1/012018

hand model option and the focus of this project is | on electronics | structure and | embedded
device coding, not 3D modelling. There is various | type of open-source prosthetic | hands
printed in 3D available on the Internet. Five DC motors actuate the hand, one for each finger plus one for the thumb-opposition. Motors and sensors are scattered all over the house. The built-in
control system contains a gesture control subsystem and a visual subsystem. The | motion
control subsystem is important as the sensory subsystem for both | the amputee using a
prosthetic and its control algorithms. The aim of this project to develop a low-cost, 3D prosthetic hand-printed using EMG. Though the final device has been fulfilled most of the initial steps, there are other aspects of the new layout that need to be rebuilt for real- life use cases.

### 7. Current Technology

There are several different trans-radial commercial prosthetics available nowadays and a lot of
the hand of the prosthesis is also under production. This segment will | discuss, | analyze
and examine a few groundbreaking designs available in today's market.

References

[1] S. Hasan, et. al., “Wearable Mind Thoughts Controlled Open Source 3D Printed Arm with Embedded Sensor Feedback System”, CHIRA 2018 - 2nd International Conference on Computer-Human Interaction Research and Applications, 2018.
[2] Ivan I. Borisov et. al., “Prototyping of EMG — Controlled Prosthetic Hand with Sensory System”, IFAC-Papers OnLine, Elsevier, Volume 50, Issue 1, 2017, pp. 16027-16031.
[3] S. Sudharshan et. al., “Design and Development of EMG Controlled Prosthetics Limb”, Procedia Engineering, Elsevier, Vol. 38, 2012, pp. 3547 — 3551.
[4] Linda Resnik et. al., “Evaluation of EMG pattern recognition for upper limb prosthesis control: a case study in comparison with direct myoelectric control”, Journal of NeuroEngineering and Rehabilitation, Vol. 15, No. 23, 2018.
[5] Ke Xu et. al., “A prosthetic arm based on EMG pattern recognition”, IEEE International Conference on Robotics and Biomimetics, 2016.
[6] “Real-Time EMG Based Pattern Recognition Control for Hand Prostheses: A Review on
Existing | Methods, | Challenges | and | Future | Implementation”, | Sensors | (Basel),
Multidisciplinary Digital Publishing Institute (MDPI), vol. 19, No. 20, 2019.
[7] IoT Book: The Internet of Things” by Samuel Greengard, Precision: Principles, Practices, and Solutions for the Internet of Things” by Timothy.

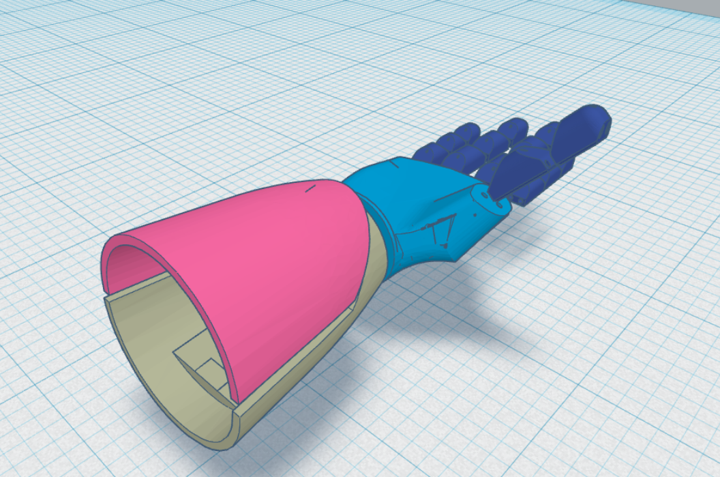
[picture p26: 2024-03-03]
Prosthetic_hand/3D Files Robo Hand/Screenshot 2024-03-03 145712.png

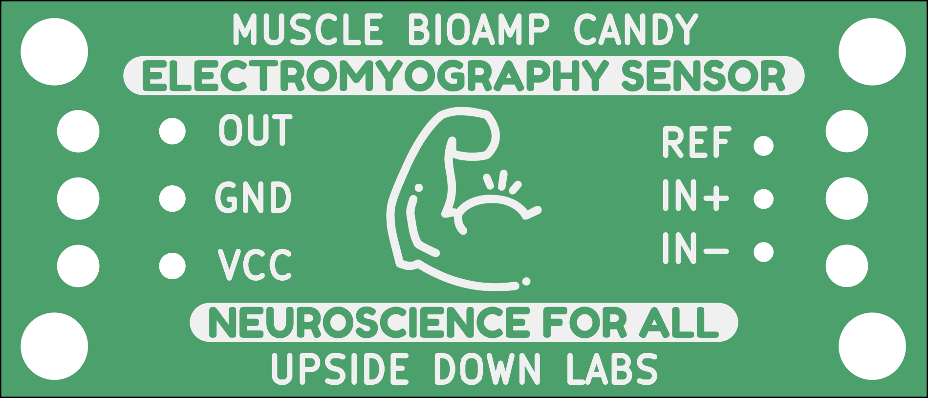
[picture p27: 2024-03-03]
Candy/graphics/board/PCBback.png

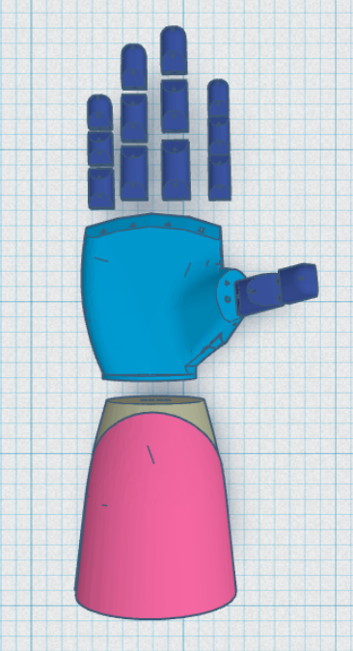
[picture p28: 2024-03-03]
Prosthetic_hand/3D Files Robo Hand/Screenshot 2024-03-03 145328.png

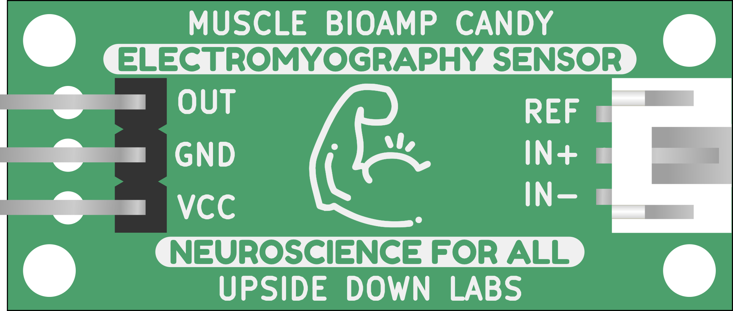
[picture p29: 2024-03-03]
Candy/graphics/board/back.png

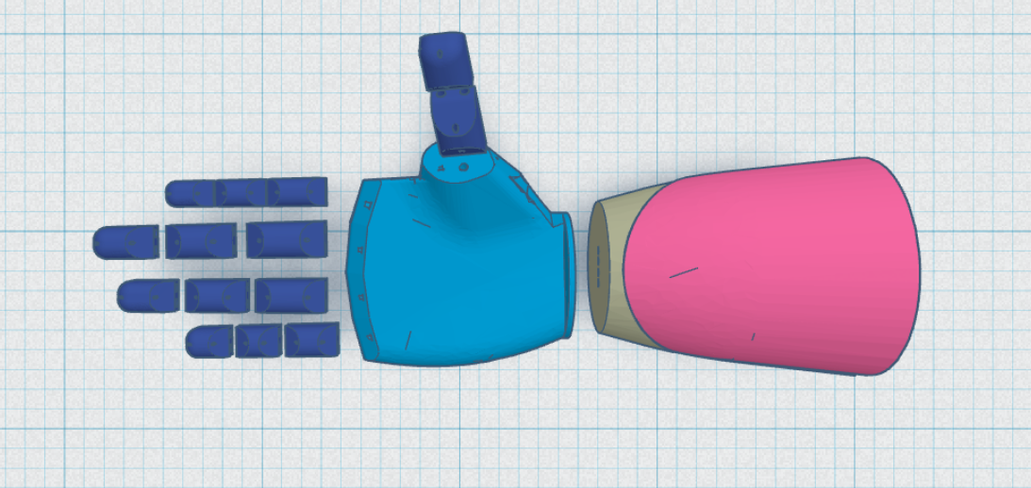
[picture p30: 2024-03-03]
Prosthetic_hand/3D Files Robo Hand/Screenshot 2024-03-03 145422.png

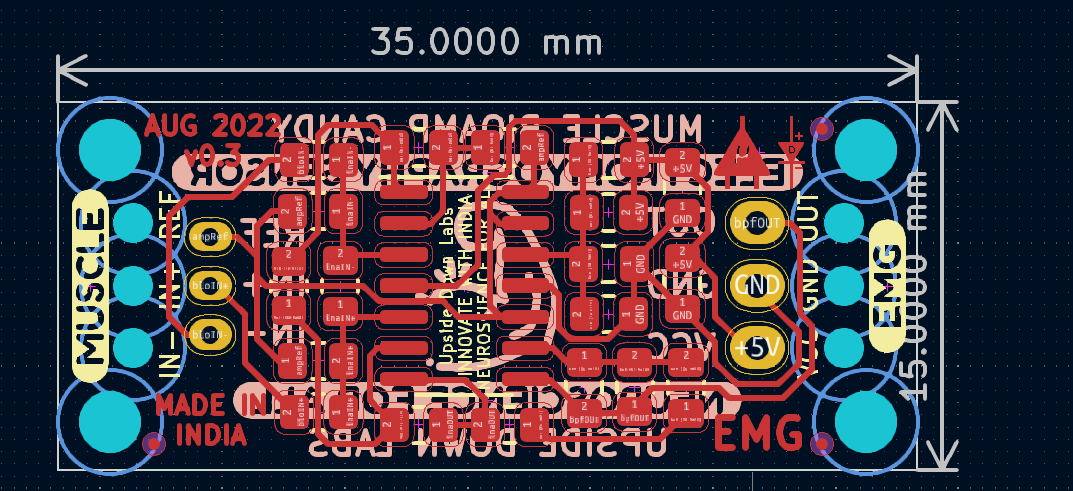
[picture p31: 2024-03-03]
Candy/graphics/board/dimensions.png

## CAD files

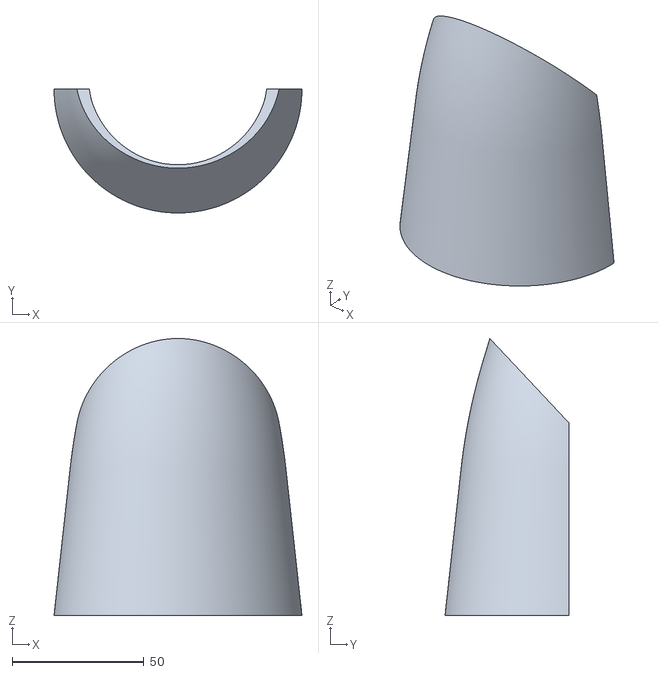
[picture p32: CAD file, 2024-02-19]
Prosthetic_hand/3D Files Robo Hand/Arm_Cover.stl
94.0 x 47.0 x 105.0

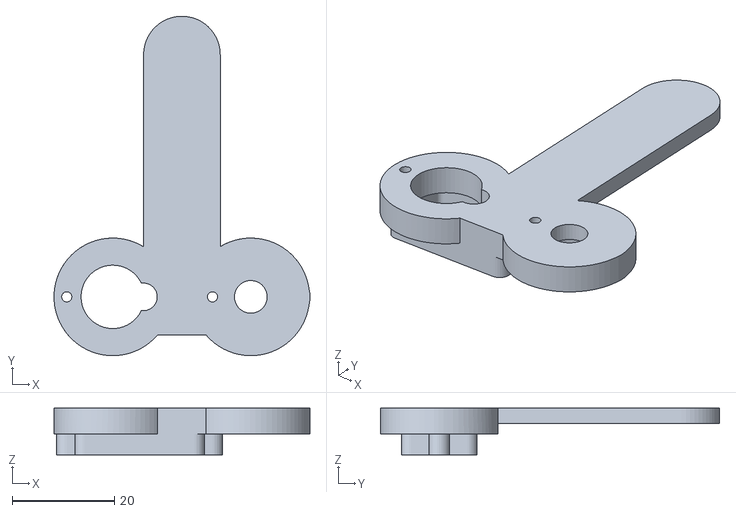
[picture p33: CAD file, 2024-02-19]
Prosthetic_hand/3D-Claw/Base.stl
50.1 x 66.4 x 9.10

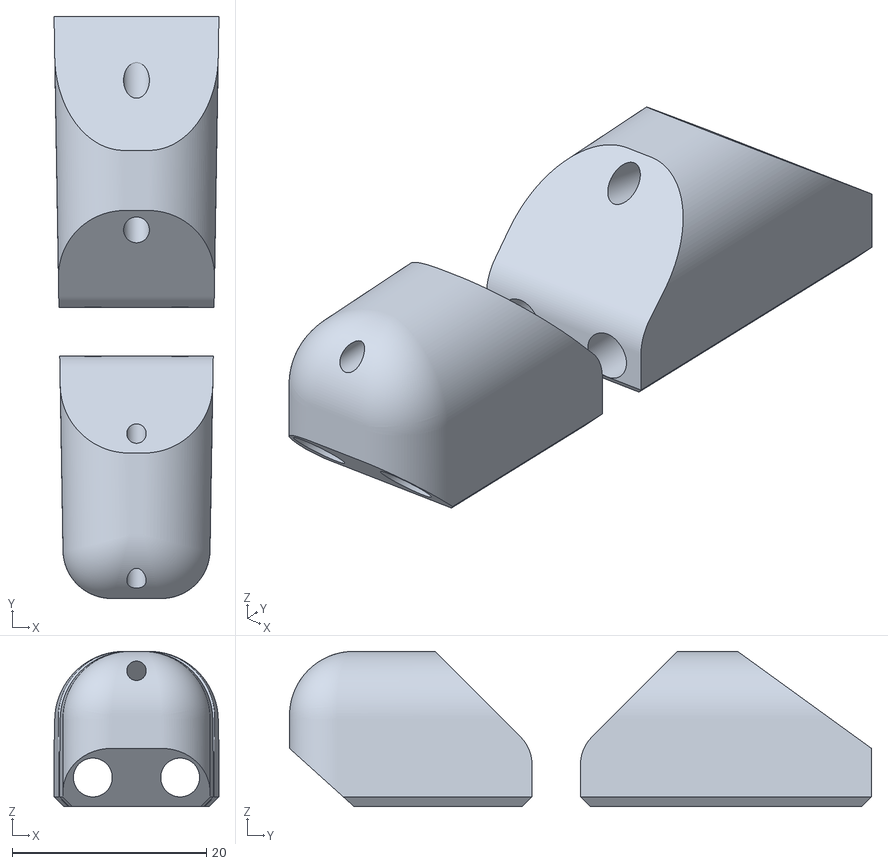
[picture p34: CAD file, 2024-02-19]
Prosthetic_hand/3D Files Robo Hand/Finger_Thumb.stl
17.0 x 60.0 x 16.0

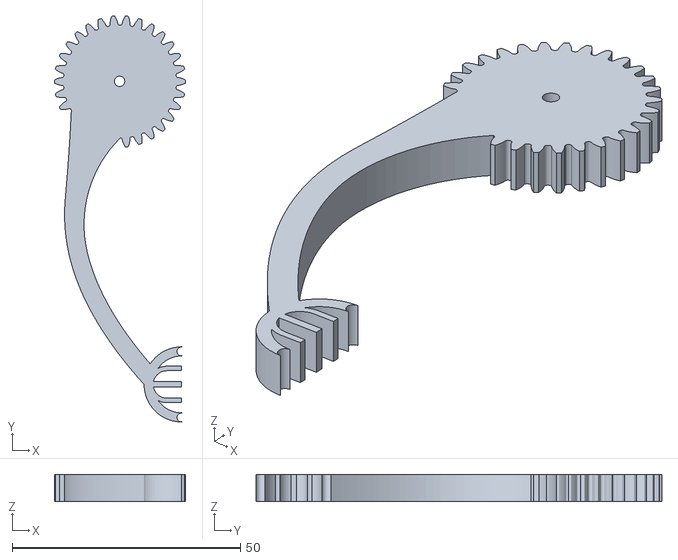
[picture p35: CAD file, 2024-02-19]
Prosthetic_hand/3D-Claw/arm 1.stl
28.8 x 88.9 x 6.00

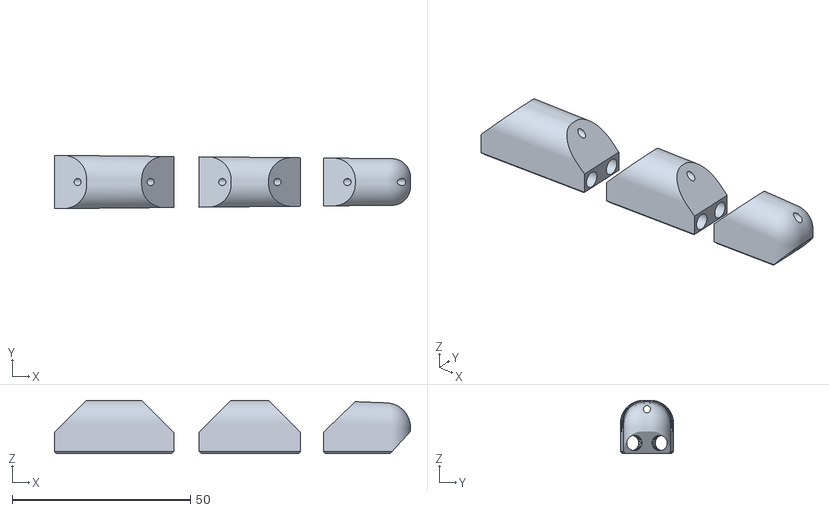
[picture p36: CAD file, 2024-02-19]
Prosthetic_hand/3D Files Robo Hand/Finger_Middle.stl
100.0 x 15.0 x 15.0

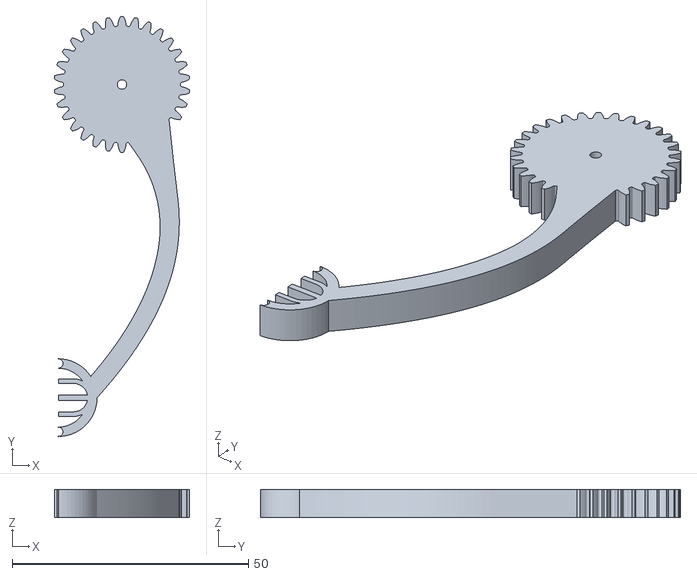
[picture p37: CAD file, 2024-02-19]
Prosthetic_hand/3D-Claw/arm 2.stl
28.7 x 89.0 x 6.00

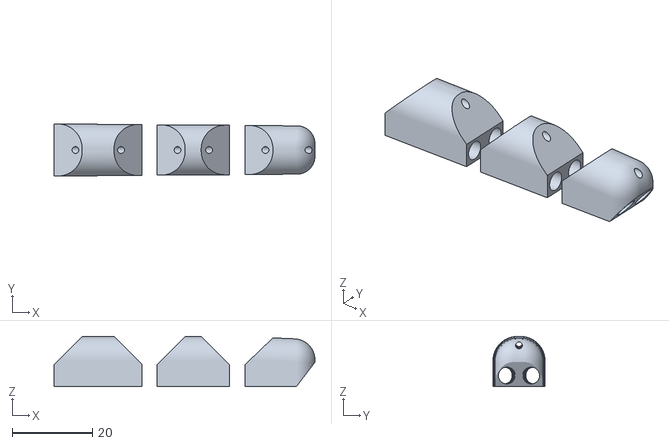
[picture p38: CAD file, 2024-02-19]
Prosthetic_hand/3D Files Robo Hand/Finger_Pinky.stl
65.2 x 13.0 x 12.5

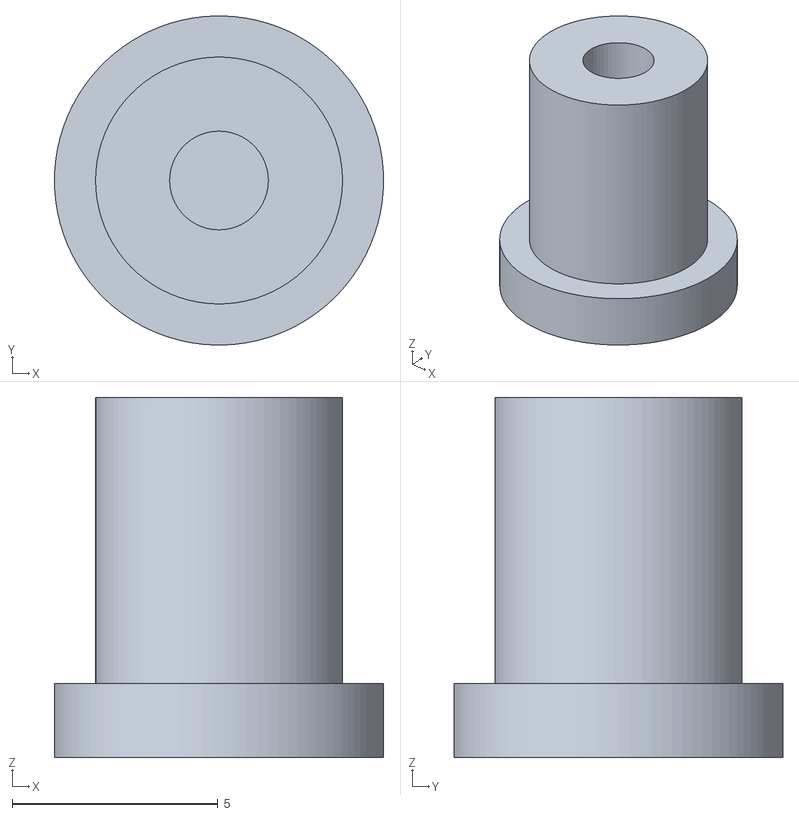
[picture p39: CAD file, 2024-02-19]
Prosthetic_hand/3D-Claw/gear connector.stl
8.00 x 8.00 x 8.75

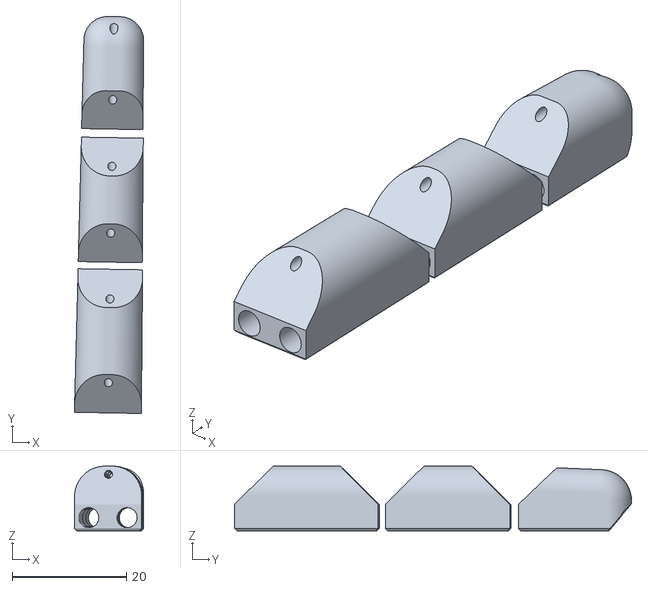
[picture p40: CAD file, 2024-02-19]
Prosthetic_hand/3D Files Robo Hand/Finger_Index.stl
12.1 x 69.4 x 11.3

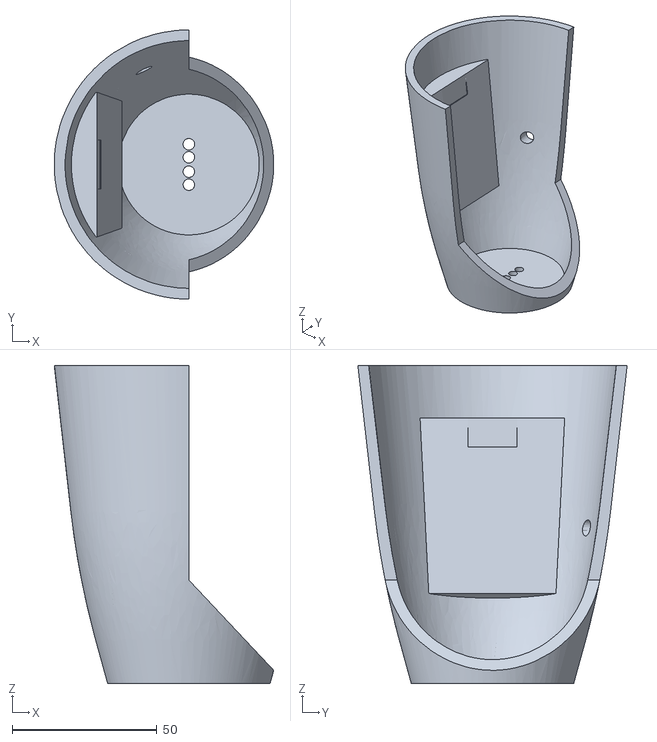
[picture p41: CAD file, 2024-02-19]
Prosthetic_hand/3D Files Robo Hand/Arm.stl
75.9 x 93.1 x 109.9

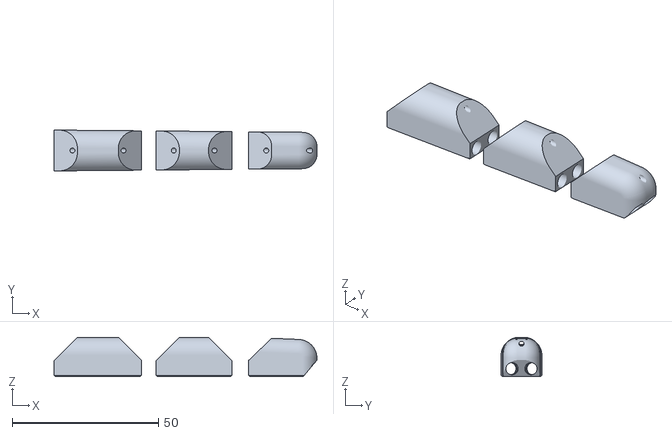
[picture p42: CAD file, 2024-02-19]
Prosthetic_hand/3D Files Robo Hand/Finger_Ring.stl
90.0 x 14.0 x 13.5

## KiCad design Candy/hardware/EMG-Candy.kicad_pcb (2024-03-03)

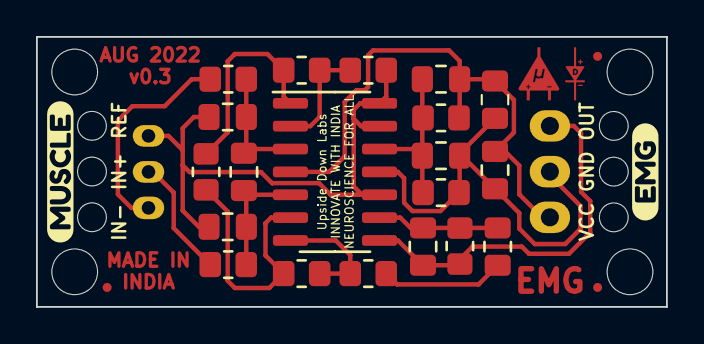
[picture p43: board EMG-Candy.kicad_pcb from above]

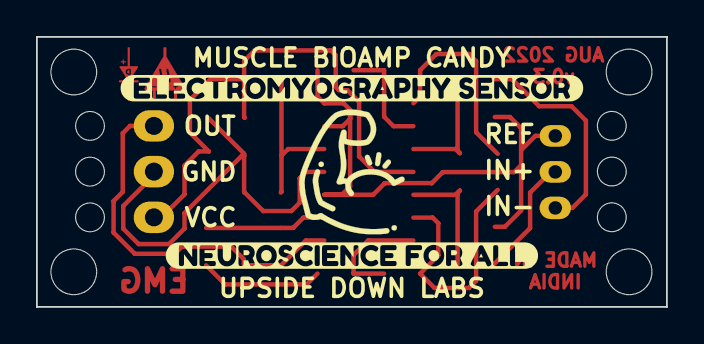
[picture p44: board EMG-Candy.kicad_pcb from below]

Board: 2 copper layers, 35.0 x 15.0 mm, 39 parts (4 on the bottom side), 13 nets.

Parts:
C1, C3: 100pF; C_0805_2012Metric_Pad1.18x1.45mm_HandSolder
C2, C7: 1nF; C_0805_2012Metric_Pad1.18x1.45mm_HandSolder
C4, C8: 100nF; C_0805_2012Metric_Pad1.18x1.45mm_HandSolder
C5, C6: 2.2uF; C_0805_2012Metric_Pad1.18x1.45mm_HandSolder
C9: 47uF; C_0805_2012Metric_Pad1.18x1.45mm_HandSolder
F1**, F2**, F3**: Fiducial_0.5mm_Mask1mm
H1, H2, H3, H4, H5, H6, H7, H8, H9, H10: MountingHole; MountingHole_2.1mm
J1: IO; PinHeader_1x03_P2.54mm_Horizontal
J3: BioAmp_input; JST_PH_S3B-PH-K_1x03_P2.00mm_Horizontal
R1, R2: 1K; R_0805_2012Metric_Pad1.20x1.40mm_HandSolder
R3, R4: 1M; R_0805_2012Metric_Pad1.20x1.40mm_HandSolder
R5: 1k; R_0805_2012Metric_Pad1.20x1.40mm_HandSolder
R6: 220K; R_0805_2012Metric_Pad1.20x1.40mm_HandSolder
R7, R10: 100k; R_0805_2012Metric_Pad1.20x1.40mm_HandSolder
R8, R9: 10k; R_0805_2012Metric_Pad1.20x1.40mm_HandSolder
U1: Amp; SOIC-14_3.9x8.7mm_P1.27mm
kibuzzard-62E8CB67: G***; kibuzzard-62E8CB67
kibuzzard-626BB171: G***; kibuzzard-626BB171
kibuzzard-626FA17E: G***; kibuzzard-626FA17E
kibuzzard-626FA157: G***; kibuzzard-626FA157

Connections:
+5V: C4.2, C8.2, C9.2, R3.2, U1.4 (V+)
GND: C5.1, C8.1, C9.1, R4.1, U1.11 (V-)
unnamed: C4.1, C5.2, R3.1, R4.2, U1.12 (+)
unnamed: C6.1, R5.1
unnamed: C6.2, C7.1, R6.2, U1.9 (-)
unnamed: R7.1, R8.2, U1.2 (-)
unnamed: R8.1, R9.2, U1.1
unnamed: R9.1, R10.2, U1.6 (-)
ampRef: C1.2, C3.1, R7.2, U1.10 (+), U1.13 (-), U1.14
bpfOUT: C7.2, R6.1, U1.8
inaIN+: C2.1, C3.2, R2.1, U1.5 (+)
inaIN-: C1.1, C2.2, R1.1, U1.3 (+)
inaOUT: R5.2, R10.1, U1.7

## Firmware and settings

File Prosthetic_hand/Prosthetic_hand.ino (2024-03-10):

// Claw Controller - BioAmp EXG Pill
// Use for Bionic (wolverine) claw as well
// https://github.com/upsidedownlabs/BioAmp-EXG-Pill

// Upside Down Labs invests time and resources providing this open source code,
// please support Upside Down Labs and open-source hardware by purchasing
// products from Upside Down Labs!

// Copyright (c) 2021 - 2023 Upside Down Labs - contact@upsidedownlabs.tech

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
#if defined(ESP32) 
  // For ESP32 Servo library
  #include <ESP32Servo.h>
#else
  // Arduino Servo library
  #include <Servo.h>
#endif

// Samples per second
#define SAMPLE_RATE 500

// Make sure to set the same baud rate on your Serial Monitor/Plotter
#define BAUD_RATE 115200

// Change if not using A0 analog pin
#define INPUT_PIN A0

// envelopeee buffer size
// High value -> smooth but less responsive
// Low value -> not smooth but responsive
#define BUFFER_SIZE 64

// Initializing 5 servo fingers
Servo thumb;
Servo index;
Servo midd;
Servo ring;
Servo pinky;

// Servo pin (Change as per your connection)
#define THUMB_PIN 2 
#define INDEX_PIN 3
#define MIDD_PIN 5
#define RING_PIN 6
#define PINKY_PIN 4

// Pin for writing
#define writePin 10
#define writeEN 11

// EMG Threshold value, different for each user
// Check by plotting EMG envelopee data on Serial plotter
#define EMG_THRESHOLD 0

// Servo open & close angles
#define SERVO_OPEN 0
#define SERVO_CLOSE 180

// EMG Envelope baseline value
// Minimum value without flexing hand
#define EMG_ENVELOPE_BASELINE 4

// EMG Envelope divider
// Minimum value increase required to turn on a single LED
#define EMG_ENVELOPE_DIVIDER 4


Servo servo;
// Servo toggle flag
bool flag = 0;
// Last gesture timestamp
unsigned long lastGestureTime = 0;
// Delay between two actions
unsigned long gestureDelay = 240;

int circular_buffer[BUFFER_SIZE];
int data_index, sum;

// Muscle BioAmp Shield v0.3 LED pin numbers in-order
// int led_bar[] = {8, 9, 10, 11, 12, 13};
// int total_leds = sizeof(led_bar) / sizeof(led_bar[0]);

void setup() {
  // Serial connection begin
  Serial.begin(BAUD_RATE);
  // Initialize all the led_bar
    // for (int i = 0; i < total_leds; i++) {
    //   pinMode(led_bar[i], OUTPUT);
    // }
    pinMode(writePin,INPUT);
    pinMode(writeEN,INPUT);
 
   thumb.attach(THUMB_PIN);
   thumb.write(0);
   index.attach(INDEX_PIN);
   index.write(0);
   midd.attach(MIDD_PIN);
   midd.write(0);
   ring.attach(RING_PIN);
   ring.write(0);
   pinky.attach(PINKY_PIN);
   pinky.write(0);
}

void loop() {
  // Calculate elapsed time
  static unsigned long past = 0;
  unsigned long present = micros();
  unsigned long interval = present - past;
  past = present;

  // Run timer
  static long timer = 0;
  timer -= interval;

  // Sample and get envelope
  if(timer < 0) {
    timer += 1000000 / SAMPLE_RATE;
   
    // RAW EMG Values
    int sensor_value = analogRead(INPUT_PIN);
    
    // Filtered EMG
    int signal = EMGFilter(sensor_value);
    
    // EMG envelopee
    int envelope = getEnvelope(abs(signal));

    // Update LED bar graph
    // for(int i = 0; i<=total_leds; i++){
    //   if(i>(envelope/EMG_ENVELOPE_DIVIDER - EMG_ENVELOPE_BASELINE)){
    //       digitalWrite(led_bar[i], LOW);
    //   } else {
    //       digitalWrite(led_bar[i], HIGH);
    //   }
    // }
    int writePin_value=digitalRead(writePin);
    int write_value=digitalRead(writeEN); 
    if(write_value==HIGH){
      if(writePin_value==HIGH){
            // Close all servos
          ring.write(0);
          delay(250);
          thumb.write(180);
          index.write(180);
          midd.write(180);
          pinky.write(0);
          delay(100);
          Serial.println(writePin);
      }
      else{
        ring.write(0);
        delay(250);
        thumb.write(0);
        index.write(0);
        midd.write(0);
        pinky.write(0);
          flag = 0;
          lastGestureTime = millis();
          delay(100);
      }
      
    }
    else{
      if(envelope > EMG_THRESHOLD) {
        if((millis() - lastGestureTime) > gestureDelay){
        if(flag == 1){
          ring.write(0);
          delay(250);
          thumb.write(0);
          index.write(0);
          midd.write(0);
          pinky.write(0);
          
          flag = 0;
          lastGestureTime = millis();
          delay(100);
        }
        else {
          // Close all servos
          ring.write(180);
          delay(250);
          thumb.write(180);
          index.write(180);
          midd.write(180);
          pinky.write(180);
          flag = 1;
          lastGestureTime = millis();
          delay(100);
        }
        }
      } 
    }
    
    
    // EMG Raw signal
    // Serial.print(signal);
    // // Data seprator
    // Serial.print(",");
    // EMG envelopeee
    Serial.println(envelope);

  }
}

// envelope detection algorithm
int getEnvelope(int abs_emg){
  sum -= circular_buffer[data_index];
  sum += abs_emg;
  circular_buffer[data_index] = abs_emg;
  data_index = (data_index + 1) % BUFFER_SIZE;
  return (sum/BUFFER_SIZE) * 2;
}

// Band-Pass Butterworth IIR digital filter, generated using filter_gen.py.
// Sampling rate: 500.0 Hz, frequency: [74.5, 149.5] Hz.
// Filter is order 4, implemented as second-order sections (biquads).
// Reference: 
// https://docs.scipy.org/doc/scipy/reference/generated/scipy.signal.butter.html
// https://courses.ideate.cmu.edu/16-223/f2020/Arduino/FilterDemos/filter_gen.py
float EMGFilter(float input)
{
  float output = input;
  {
    static float z1, z2; // filter section state
    float x = output - 0.05159732*z1 - 0.36347401*z2;
    output = 0.01856301*x + 0.03712602*z1 + 0.01856301*z2;
    z2 = z1;
    z1 = x;
  }
  {
    static float z1, z2; // filter section state
    float x = output - -0.53945795*z1 - 0.39764934*z2;
    output = 1.00000000*x + -2.00000000*z1 + 1.00000000*z2;
    z2 = z1;
    z1 = x;
  }
  {
    static float z1, z2; // filter section state
    float x = output - 0.47319594*z1 - 0.70744137*z2;
    output = 1.00000000*x + 2.00000000*z1 + 1.00000000*z2;
    z2 = z1;
    z1 = x;
  }
  {
    static float z1, z2; // filter section state
    float x = output - -1.00211112*z1 - 0.74520226*z2;
    output = 1.00000000*x + -2.00000000*z1 + 1.00000000*z2;
    z2 = z1;
    z1 = x;
  }
  return output;
}

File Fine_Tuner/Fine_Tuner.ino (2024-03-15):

#include <Servo.h>

// Initializing 5 servo fingers
Servo thumb;
Servo index;
Servo midd;
Servo ring;
Servo pinky;

// Servo pin (Change as per your connection)
#define THUMB_PIN 2 
#define INDEX_PIN 3
#define MIDDLE_PIN 5
#define RING_PIN 6
#define PINKY_PIN 4

void setup() {
  // Attaching each servo to its respective pin
  thumb.attach(THUMB_PIN);
  index.attach(INDEX_PIN);
  midd.attach(MIDDLE_PIN);
  ring.attach(RING_PIN);
  pinky.attach(PINKY_PIN);
  Serial.begin(9600);
}

void loop() {
  // Open all servos
  Serial.print("0\n");
  ring.write(0);
  // delay(250);
  thumb.write(0);
  index.write(0);
  midd.write(0);
  pinky.write(0);
 
  
  delay(1000); // 2-second delay
  
  // Close all servos
  Serial.print("180\n");
  ring.write(180);
  // delay(250);
  thumb.write(180);
  index.write(180);
  midd.write(180);
  pinky.write(180);
  
  delay(1000); // 2-second delay
}

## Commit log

2024-03-03 New Files
    [EMG-Candy.kicad_pcb, EMG-Candy.kicad_sch]
2024-03-03 Sunday Night Push
    [Arm.stl, Arm_Cover.stl, Finger_Index.stl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]
